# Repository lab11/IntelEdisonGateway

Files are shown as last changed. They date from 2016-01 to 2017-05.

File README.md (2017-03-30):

# Intel Edison-based Gateway
<!--
A gateway design based on Intel Edison, which features two 802.15.4
radios, Ethernet controller, micro SD slot, built-in Wifi and BLE radios.

<img src="https://raw.githubusercontent.com/lab11/IntelEdisonGateway/master/images/edison_front.png" alt="Gateway Edison" width="25%;">&nbsp;&nbsp;&nbsp;&nbsp;&nbsp;&nbsp;&nbsp;&nbsp;&nbsp;
<img src="https://raw.githubusercontent.com/lab11/IntelEdisonGateway/master/images/edison_case_1000x629.jpg" alt="Gateway Edison" width="35%;">
-->
Second generation of Intel Edison Gateway. The gateway supports a wide range 
of radios / connectivity including 802.15.4, Wifi, BLE, Ethernet, LTE and GPS.
The precompiled linux kernel [image](https://github.com/lab11/IntelEdisonGateway/tree/master/kernel_patch/3.10.98/kernel_image) 
(based on Intel release, version 3.10.98) comes with necessary drivers for the
cellular modem and Ethernet controller.

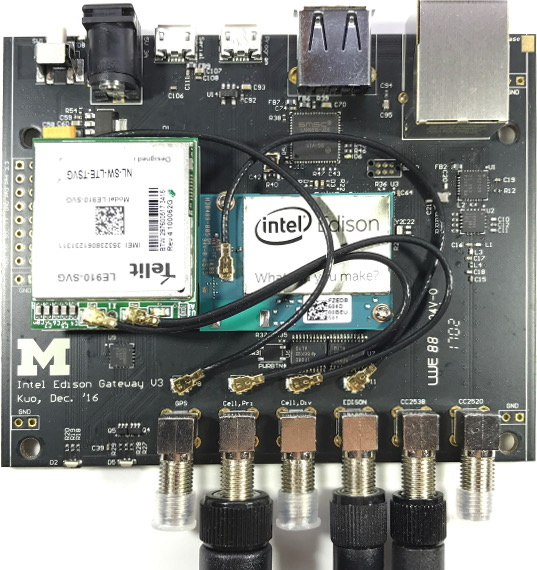
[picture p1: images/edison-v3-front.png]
Gateway Edison
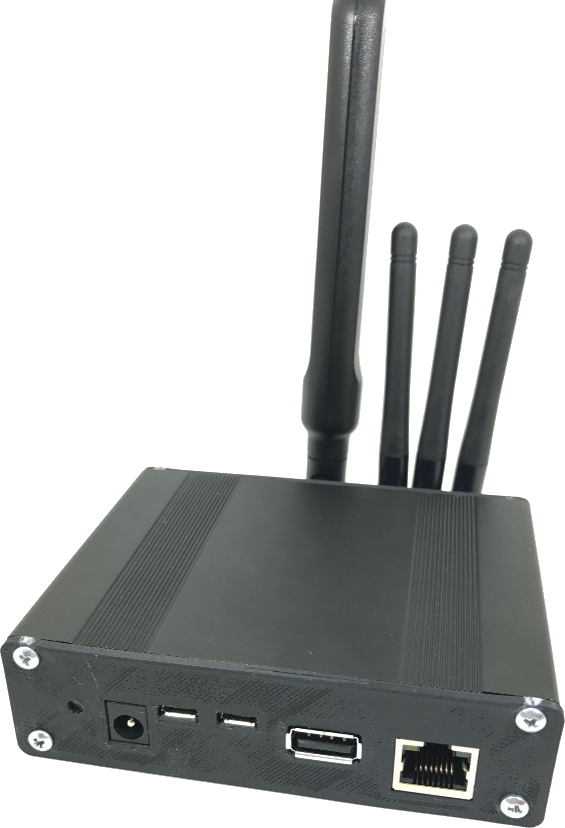
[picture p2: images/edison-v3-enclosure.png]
Gateway Edison Enclosure
 

The onboard cellular modem is [NimbeLink Skywire 4G LTE](http://nimbelink.com/skywire-cellular-modem-lte/),
which supports 100 Mb downlink and 50 Mb uplink and integrated GPS radio.
The cellular radio speaks Qualcomm MSM Interface (QMI), which allows the radio
to be mounted as a network adapter directly in Linux with [libqmi](https://www.freedesktop.org/wiki/Software/libqmi/).

The board is designed to fit in the off-the-shelf extruded aluminum enclosure 
[B2-080BK](http://www.boxenclosures.com/category/product_details.html?product__id=258909).

<!--
[LGSInnovations](https://github.com/LGSInnovations/Edison-Ethernet) has great
documentation of how to use LAN9512 on ubilinux.
The kernel module for smsc95xx (Ethernet controller) can be found [here](https://github.com/LGSInnovations/Edison-Ethernet/releases),
as well as the [installation guide](https://github.com/LGSInnovations/Edison-Ethernet/blob/master/guides/installation.md).

[edison_front]: https://github.com/lab11/IntelEdisonGateway/blob/master/images/edison_front.png "Front"

Pin Out
-------

Header on the left side of the PCB:

| Pin | Signal | | Signal | Pin |
|-----|---|---|---|-----|
| 1 | MISO | | MOSI | 2 |
| 3 | SCLK | | !CS1 | 4 |
| 5 | SDA | | SCL | 6 |
| 7 | RX | | TX | 8 |
| 9 | GP46 | | GP45 | 10  |
| 11  | PA5 | | GP44 | 12  |
| 13  | PA6 | | PA3 | 14  |
| 15  | PA7 | | PA4 | 16  |
| 17  | GND | | GND | 18  |
-->

Pin Out
-------

Header on the left side of the PCB. This is changed from the previous version:

| Pin | Signal  | | Signal  | Pin |
|-----|---|---|---|-----|
| 1 | VCC3.3  | | VSYS3.9 | 2 |
| 3 | PA4 | | PA5 | 4 |
| 5 | PA3 | | GP46 | 6 |
| 7 | GND | | GND | 8 |
| 9 | UART TX | | UART RX | 10  |
| 11  | I2C SCL | | I2C SDA | 12  |
| 13  | SPI CS1 | | SPI CLK | 14  |
| 15  | MOSI | | MISO | 16  |

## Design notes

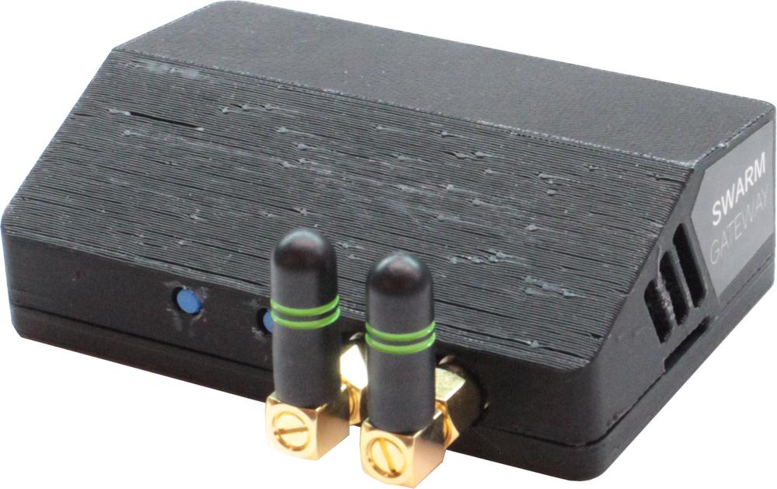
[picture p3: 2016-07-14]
images/edison_case_1000x629.jpg

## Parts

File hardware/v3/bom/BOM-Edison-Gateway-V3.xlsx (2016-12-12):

Designator | Value | Quantity | Tolerance | Rated | Footprint | Description | DigiKey part number | Note
ANT1, ANT2, ANT3, ANT4, ANT5, ANT6 |  | 6 |  |  | 619540-1 | CONN SMA JACK | A120734-ND (https://octopart-clicks.com/click/altium?manufacturer=TE%20Connectivity%20AMP%20Connectors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)
B1 |  | 1 |  |  | 2450BM15A0002 | 2.45 GHz Balun for TI CC253X | 712-1536-1-ND (https://octopart-clicks.com/click/altium?manufacturer=Johanson%20Technology%20Inc.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)
C1, C49, C54, C58 | 100u | 4 | 20% | 10 V | 1206 - POLAR MARKING | 100µF ±20% Molded Tantalum Capacitors 10V 1206 | 478-6251-1-ND (https://octopart-clicks.com/click/altium?sku=478-6251-1-ND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)
C2, C5, C7, C8, C25, C51, C53, C55, C56, C57, C60, C61, C70, C93, C95, C97, C101, C103, C105, C107 | 10u | 20 | 20% | 16 V | 0603 | 10µF ±20% 16V Ceramic Capacitor X6S 0603 | 490-7198-1-ND (https://octopart-clicks.com/click/altium?sku=490-7198-1-ND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)
C3, C4, C6, C9, C13, C14, C19, C24, C26, C32, C33, C34, C35, C36, C37, C38, C39, C63, C64, C65, C66, C67, C68, C69, C71, C72, C74, C75, C76, C77, C78, C79, C80, C81, C82, C83, C84, C85, C86, C87, C88, C89, C91, C106, C108, C111 | 0.1u | 46 | 10% | 16 V | 0402 | 0.10µF ±10% 16V Ceramic Capacitor X7R 0402 | 490-3261-1-ND (https://octopart-clicks.com/click/altium?sku=490-3261-1-ND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)
C10, C20, C21, C30, C31 | 12p | 5 | 2% | 50 V | 0402 | 12pF ±2% 50V Ceramic Capacitor C0G, NP0 0402 | 712-1256-1-ND (https://octopart-clicks.com/click/altium?manufacturer=Johanson%20Technology%20Inc.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)
C11, C29 | 1000p | 2 | 5% | 50 V | 0402 | 1000pF ±5% 50V Ceramic Capacitor C0G, NP0 0402 | 445-6846-1-ND (https://octopart-clicks.com/click/altium?manufacturer=TDK%20Corporation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)
C12, C40, C52, C59, C62, C73, C92, C94, C96, C100, C102, C104 | 1u | 12 | 10% | 16 V | 0402 | 1µF ±10% 16V Ceramic Capacitor X6S 0402 | 445-9086-1-ND (https://octopart-clicks.com/click/altium?manufacturer=TDK%20Corporation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)
C15 | 18p | 1 | 2% | 50 V | 0402 | 18pF ±2% 50V Ceramic Capacitor C0G, NP0 0402 | 712-1264-1-ND (https://octopart-clicks.com/click/altium?manufacturer=Johanson%20Technology%20Inc.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)
C16, C17 | 2.2p | 2 | 5% | 50 V | 0402 | 2.2pF ±0.1pF 50V Ceramic Capacitor C0G, NP0 | 712-1279-1-ND (https://octopart-clicks.com/click/altium?manufacturer=Johanson%20Technology%20Inc.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)
C18 | 0.2p | 1 | 20% | 50 V | 0402 | 0.20pF ±0.05pF 50V Ceramic Capacitor C0G, NP0 0402 | 712-1244-1-ND (https://octopart-clicks.com/click/altium?manufacturer=Johanson%20Technology%20Inc.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)
C22, C23 | 22p | 2 | 2% | 50 V | 0402 | 22pF ±2% 50V Ceramic Capacitor C0G, NP0 0402 | 712-1274-1-ND (https://octopart-clicks.com/click/altium?manufacturer=Johanson%20Technology%20Inc.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)
C27, C28, C109, C110 | 47p | 4 | 5% | 50 V | 0402 | 47pF ±5% 50V Ceramic Capacitor C0G, NP0 0402 | 709-1121-1-ND (https://octopart-clicks.com/click/altium?manufacturer=Johanson%20Dielectrics%20Inc.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)
C41, C42 | 33p | 2 | 5% | 50 V | 0402 | 33pF ±5% 50V Ceramic Capacitor C0G, NP0 0402 | 490-5936-1-ND (https://octopart-clicks.com/click/altium?sku=490-5936-1-ND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)
~~C43~~ | ~~10000p~~ | ~~1~~ | ~~10%~~ | ~~16 V~~ | ~~0402~~ | ~~10000pF ±10% 16V Ceramic Capacitor X7R 0402~~ | ~~490-1313-1-ND~~ (https://octopart-clicks.com/click/altium?sku=490-1313-1-ND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) | ~~DNP~~
C44 | 0.022u | 1 | 10% | 50 V | 0402 | 0.022µF ±10% 50V Ceramic Capacitor X7R 0402 | 490-3884-1-ND (https://octopart-clicks.com/click/altium?sku=490-3884-1-ND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)
C45, C46, C47, C48 | 15p | 4 | 5% | 25 V | 0402 | 15pF ±5% 25V Ceramic Capacitor C0G, NP0 0402 | 490-8171-1-ND (https://octopart-clicks.com/click/altium?sku=490-8171-1-ND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)
C50 | 22u | 1 | 20% | 16 V | 1206 | 22µF ±20% 16V Ceramic Capacitor X5R 1206 | 1276-2728-1-ND (https://octopart-clicks.com/click/altium?sku=1276-2728-1-ND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)
C90 | 220p | 1 | 10% | 50 V | 0402 | 220pF ±10% 50V Ceramic Capacitor X7R 0402 | 399-1030-1-ND (https://octopart-clicks.com/click/altium?sku=399-1030-1-ND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)
C98, C99 | 150u | 2 | 10% | 10 V | 2312 | 150µF ±10% Molded Tantalum Capacitors 10V 2312 | 478-2352-1-ND (https://octopart-clicks.com/click/altium?sku=478-2352-1-ND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)
D1, D3 | Green | 2 |  |  | 0402 - LED | Green 571nm LED Indication - Discrete 2V 0402 (1005 Metric) | 754-1811-1-ND (https://octopart-clicks.com/click/altium?sku=754-1811-1-ND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)
D2, D5, D9 | RGB | 3 |  |  | HSMF | Red, Green, Blue (RGB) 626nm Red, 572nm Green, 470nm Blue LED Indication - Discrete 1.9V Red, 2V Green, 3.4V Blue 4-SMD | 516-2232-1-ND (https://octopart-clicks.com/click/altium?sku=516-2232-1-ND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)
D4, D6 | Orange | 2 |  |  | 0402 - LED | Orange 605nm LED Indication - Discrete 2.1V 0402 | 846-1200-1-ND (https://octopart-clicks.com/click/altium?sku=846-1200-1-ND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)
D7 |  | 1 |  |  | SMAZ5V1 | Zener Diode 5.6V 1W ±5% Surface Mount SMA | SMAZ5V6-FDICT-ND (https://octopart-clicks.com/click/altium?manufacturer=Diodes%20Incorporated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)
D8 | Blue | 1 |  |  | APGA1602 | Blue 463nm LED Indication - Discrete 2.8V 2-SMD | 754-1821-1-ND (https://octopart-clicks.com/click/altium?sku=754-1821-1-ND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)
D10 |  | 1 |  |  | SOT23-3 | Diode Array 1Pair Common Cathode Schottky 40V 200mA (DC) Surface Mount TO-236-3, SC-59, SOT-23-3 | BAS40-05FDICT-ND (https://octopart-clicks.com/click/altium?manufacturer=Diodes%20Incorporated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)
FB1, FB2, FB3, FB4, FB5, FB6, FB7, FB8, FB9, FB10 |  | 10 |  |  | 0603 | FERRITE BEAD 220 OHM 0603 | 490-5225-1-ND (https://octopart-clicks.com/click/altium?sku=490-5225-1-ND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)
J1 |  | 1 |  |  | 2201778-1 | Micro SD Slot | A118117CT-ND (https://octopart-clicks.com/click/altium?manufacturer=TE%20Connectivity%20AMP%20Connectors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)
J2 |  | 1 |  |  | J0011D01BNL | 1x1 Tab-Down RJ45 | 553-1483-ND (https://octopart-clicks.com/click/altium?manufacturer=Pulse%20Electronics%20Corporation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)
J3 |  | 1 |  |  | PJ-102AH | CONN PWR JACK 2.1X5.5MM HIGH CUR | CP-102AH-ND (https://octopart-clicks.com/click/altium?sku=CP-102AH-ND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)
J4, J6 |  | 2 |  |  | Micro USB-B | CONN USB MICRO B RECPT SMT R/A | 609-4616-1-ND (https://octopart-clicks.com/click/altium?sku=609-4616-1-ND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)
J5 |  | 1 |  |  | 292303-2 | USB 2.0 Type A | A105221-ND (https://octopart-clicks.com/click/altium?manufacturer=TE%20Connectivity%20AMP%20Connectors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)
L1 | 4.7n | 1 |  |  | 0402 | 4.7nH Unshielded Multilayer Inductor 300mA 180 mOhm Max 0402 (1005 Metric) | 490-2618-1-ND (https://octopart-clicks.com/click/altium?sku=490-2618-1-ND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)
~~L2~~ | ~~6.8n~~ | ~~1~~ |  |  | ~~0402~~ | ~~6.8nH Unshielded Multilayer Inductor 250mA 320 mOhm Max 0402 (1005 Metric)~~ | ~~712-1419-1-ND~~ (https://octopart-clicks.com/click/altium?manufacturer=Johanson%20Technology%20Inc.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) | ~~DNP~~
L3 | 1n | 1 |  |  | 0402 | 1nH Unshielded Multilayer Inductor 300mA 100 mOhm Max 0402 (1005 Metric) | 490-1073-1-ND (https://octopart-clicks.com/click/altium?sku=490-1073-1-ND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)
L4 | 2n | 1 |  |  | 0402 | 2nH Unshielded Multilayer Inductor 300mA 120 mOhm Max 0402 (1005 Metric) | 490-6558-1-ND (https://octopart-clicks.com/click/altium?sku=490-6558-1-ND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)
L5 | 470n | 1 |  |  | 74404300047 | 470nH Shielded Wirewound Inductor 3.8A 16 mOhm Max 1919 (4848 Metric) | 732-4087-1-ND (https://octopart-clicks.com/click/altium?manufacturer=Wurth%20Electronics%20Inc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)
M1 |  | 1 |  |  | skywire | NimbeLink Skywire cat3, ATT GSM 4G modem |  | Mating connector: 950510-6102-AR (x2)
M2 |  | 1 |  |  | Intel Edison mating | Intel Edison |  | Mating connector: H124603CT-ND
~~P1, P2~~ |  | ~~2~~ |  |  | ~~TC2030-IDC-NLFP~~ | ~~TC2030-MCP-NL~~ |  | ~~Not a part~~
~~P3~~ |  | ~~1~~ |  |  | ~~2x8 header~~ | ~~100 mils standard header~~ | ~~609-3220-ND~~ (https://octopart-clicks.com/click/altium?sku=609-3220-ND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) | ~~DNP~~
~~P4, P5, P6, P7~~ |  | ~~4~~ |  |  | ~~1x2 header~~ | ~~100 mils standard header~~ | ~~3M9447-ND~~ (https://octopart-clicks.com/click/altium?sku=3M9447-ND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) | ~~DNP~~
P8, P9, P10, P11 |  | 4 |  |  | U.FL-R-SMT-1(01) | U.FL, Ultra Miniature Coaxial Connector Receptacle, Male Pin 50 Ohm Surface Mount Solder | H122041-ND (https://octopart-clicks.com/click/altium?manufacturer=Hirose%20Electric%20Co%20Ltd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)
Q1, Q3, Q4, Q5, Q6 |  | 5 |  |  | SOT-353-5 | Common Source Dual N-Channel MOSFET | DMN32D2LDF-7DICT-ND (https://octopart-clicks.com/click/altium?manufacturer=Diodes%20Incorporated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)
Q2 |  | 1 |  |  | TSOT-23 | Load Switch | SI3865DDV-T1-GE3CT-ND (https://octopart-clicks.com/click/altium?manufacturer=Vishay%20Siliconix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)
~~R1, R2, R3, R4, R7, R36~~ | ~~0~~ | ~~6~~ |  |  | ~~0402~~ | ~~RES SMD 0.0 OHM JUMPER 1/5W 0402~~ | ~~541-0.0YBCT-ND~~ (https://octopart-clicks.com/click/altium?sku=541-0.0YBCT-ND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) | ~~DNP~~
R5, R19, R22, R23, R28, R46, R48, R49, R60, R61 | 330 | 10 | 5% |  | 0402 | RES SMD 330 OHM 1% 1/16W 0402 | 541-330LCT-ND (https://octopart-clicks.com/click/altium?sku=541-330LCT-ND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)
R6, R14, R16, R17, R55, R56, R62 | 100k | 7 | 5% |  | 0402 | RES SMD 100K OHM 1% 1/16W 0402 | 541-100KLCT-ND (https://octopart-clicks.com/click/altium?sku=541-100KLCT-ND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)
R8, R9, R10, R13, R15, R30, R31, R33, R34, R35, R39, R47, R54 | 10k | 13 | 5% |  | 0402 | RES SMD 10K OHM 1% 1/16W 0402 | 541-10.0KLCT-ND (https://octopart-clicks.com/click/altium?sku=541-10.0KLCT-ND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)
R11 | 3.9k | 1 | 1% |  | 0402 | RES SMD 3.9K OHM 1% 1/16W 0402 | 311-3.90KLRCT-ND (https://octopart-clicks.com/click/altium?sku=311-3.90KLRCT-ND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)
R12, R26 | 56k | 2 | 1% |  | 0402 | RES SMD 56K OHM 1% 1/16W 0402 | 541-56.0KLCT-ND (https://octopart-clicks.com/click/altium?sku=541-56.0KLCT-ND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)
R18, R27 | 100 | 2 | 5% |  | 0402 | RES SMD 100 OHM 1% 1/16W 0402 | 541-100LCT-ND (https://octopart-clicks.com/click/altium?sku=541-100LCT-ND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)
R20, R29, R37, R53 | 200 | 4 | 5% |  | 0402 | RES SMD 200 OHM 1% 1/16W 0402 | 541-200LCT-ND (https://octopart-clicks.com/click/altium?sku=541-200LCT-ND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)
R21, R24, R58, R59 | 27 | 4 | 1% |  | 0402 | RES SMD 27 OHM 1% 1/16W 0402 | 541-27.0LCT-ND (https://octopart-clicks.com/click/altium?sku=541-27.0LCT-ND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)
R25 | 2.2k | 1 | 1% |  | 0402 | RES SMD 2.2K OHM 1% 1/16W 0402 | 541-2.20KLCT-ND (https://octopart-clicks.com/click/altium?sku=541-2.20KLCT-ND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)
R38 | 12.4k | 1 | 1% |  | 0402 | RES SMD 12.4K OHM 1% 1/16W 0402 | 311-12.4KLRCT-ND (https://octopart-clicks.com/click/altium?sku=311-12.4KLRCT-ND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)
R40, R50 | 1Meg | 2 | 1% |  | 0402 | RES SMD 1M OHM 1% 1/16W 0402 | 541-1.00MLCT-ND (https://octopart-clicks.com/click/altium?sku=541-1.00MLCT-ND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)
R41, R42, R43, R44 | 49.9 | 4 | 1% |  | 0402 | RES SMD 49.9 OHM 1% 1/16W 0402 | 541-49.9LCT-ND (https://octopart-clicks.com/click/altium?sku=541-49.9LCT-ND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)
R45 | 10 | 1 | 1% |  | 0402 | RES SMD 10 OHM 1% 1/16W 0402 | 541-10.0LCT-ND (https://octopart-clicks.com/click/altium?sku=541-10.0LCT-ND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)
R51 | 634k | 1 | 1% |  | 0402 | RES SMD 634K OHM 1% 1/16W 0402 | 541-634KLCT-ND (https://octopart-clicks.com/click/altium?sku=541-634KLCT-ND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)
R52 | 162k | 1 | 1% |  | 0402 | RES SMD 162K OHM 1% 1/16W 0402 | 541-162KLCT-ND (https://octopart-clicks.com/click/altium?sku=541-162KLCT-ND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)
R57 | 12k | 1 | 1% |  | 0402 | RES SMD 12K OHM 1% 1/16W 0402 | 541-12.0KLCT-ND (https://octopart-clicks.com/click/altium?sku=541-12.0KLCT-ND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)
SW1 |  | 1 |  |  | KT11PXSA2M | Tactile Switch SPST-NO Side Actuated Surface Mount, Right Angl | CKN1858CT-ND (https://octopart-clicks.com/click/altium?sku=CKN1858CT-ND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)
~~SW3~~ |  | ~~1~~ |  |  | ~~PTS810~~ | ~~Tactile Switches~~ | ~~CKN10504CT-ND~~ (https://octopart-clicks.com/click/altium?manufacturer=C%26K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) | ~~DNP~~
U1 |  | 1 |  |  | QFN-28 | 2.4 GHZ IEEE 802.15.4/ZIGBEE® RF TRANSCEIVER | 296-38897-1-ND (https://octopart-clicks.com/click/altium?sku=296-38897-1-ND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)
U2 |  | 1 |  |  | QFN-16 | 2.4-GHz Range Extender | 296-37475-1-ND (https://octopart-clicks.com/click/altium?sku=296-37475-1-ND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)
U3 |  | 1 |  |  | QFN56 | A Powerful System-On-Chip for 2.4-GHz IEEE 802.15.4, 6LoWPAN and ZigBee Applications | 296-35797-1-ND (https://octopart-clicks.com/click/altium?sku=296-35797-1-ND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)
U4, U14 |  | 2 |  |  | SOT23-5 | Single Bus Buffer Gate With 3-State Output | 296-11603-1-ND (https://octopart-clicks.com/click/altium?manufacturer=Texas%20Instruments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)
U5, U17 |  | 2 |  |  | QFN-20_N | USB to Full-Handshake UART Interface Chip, UHCI/OHCI/EHCI Compatible, USB 2.0 Compatible, -40 to +85 degC, 20-Pin QFN, Pb-Free, Tape and Reel | 768-1155-ND (https://octopart-clicks.com/click/altium?sku=768-1155-ND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)
U6, U7, U8 |  | 3 |  |  | TSSOP-20 | TXS0108E-Q1 8-Bit Bi-directional, Level-Shifting, Voltage Translator for Open-Drain and Push-Pull Applications | 296-42401-1-ND (https://octopart-clicks.com/click/altium?sku=296-42401-1-ND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)
U9 |  | 1 |  |  | TQFN-16 | 6-Channel High-Speed Logic-Level Translators | MAX13035EETE+-ND (https://octopart-clicks.com/click/altium?manufacturer=Maxim%20Integrated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)
U10 |  | 1 |  |  | QFN-64 | USB 2.0 Hub and 10/100 Ethernet Controller | LAN9513-JZX-ND (https://octopart-clicks.com/click/altium?sku=LAN9513-JZX-ND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)
U11 |  | 1 |  |  | VSON | 3-A Step-Down Converter With Hiccup Short-Circuit Protection In 2 × 2 QFN Package | 296-40830-1-ND (https://octopart-clicks.com/click/altium?sku=296-40830-1-ND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)
U12 |  | 1 |  |  | SOT150P700X180-5N | LP387x 0.8-A Fast Ultra-Low-Dropout Linear Regulators | LP3874EMP-3.3/NOPBCT-ND (https://octopart-clicks.com/click/altium?manufacturer=Texas%20Instruments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)
U13 |  | 1 |  |  | S-PVSON-N10 | High-Speed USB 2.0 (480-Mbps) 1:2 Multiplexer – Demultiplexer Switch With Single Enable | 296-21360-6-ND (https://octopart-clicks.com/click/altium?sku=296-21360-6-ND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)
U15, U16 |  | 2 |  |  | U-DFN3030-8 | 0.5A DUAL CHANNEL CURRENT-LIMITED POWER SWITCH WITH OUTPUT DISCHARGE | AP2152AFGEG-7DICT-ND (https://octopart-clicks.com/click/altium?manufacturer=Diodes%20Incorporated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)
Y1, Y3 |  | 2 |  |  | FA-128 | MHz Range Crystal Unit | SER4079CT-ND (https://octopart-clicks.com/click/altium?sku=SER4079CT-ND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)
Y2 |  | 1 |  |  | ABS05 | 32768 Hz SMD Low profile crystal | 535-11899-1-ND (https://octopart-clicks.com/click/altium?sku=535-11899-1-ND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)
Y4 |  | 1 |  |  | ABM8 | Crystal 25.0000MHz 20ppm 18pF 50 Ohm | 535-9140-1-ND (https://octopart-clicks.com/click/altium?sku=535-9140-1-ND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)

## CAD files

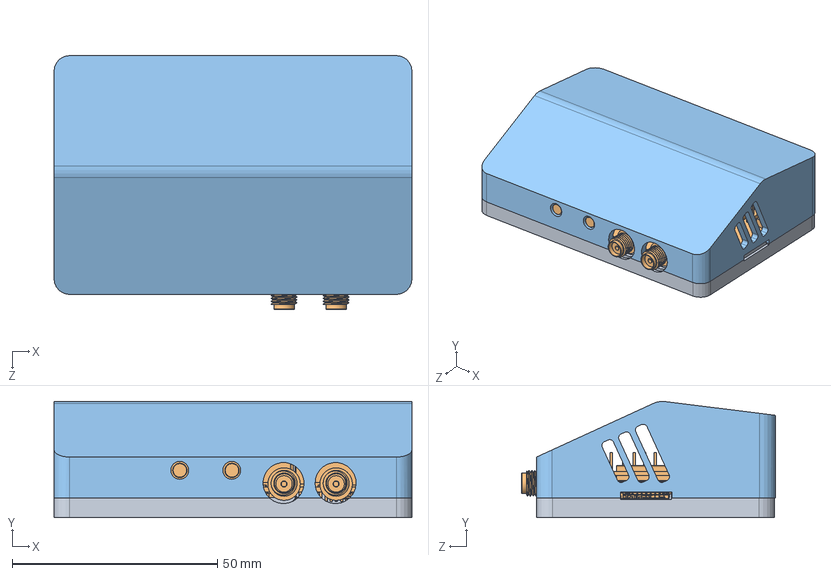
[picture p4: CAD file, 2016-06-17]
3d/gateway_in_case.SLDASM
87.3 x 28.3 x 61.9 mm
case_bottom
edison_gateway
case_top

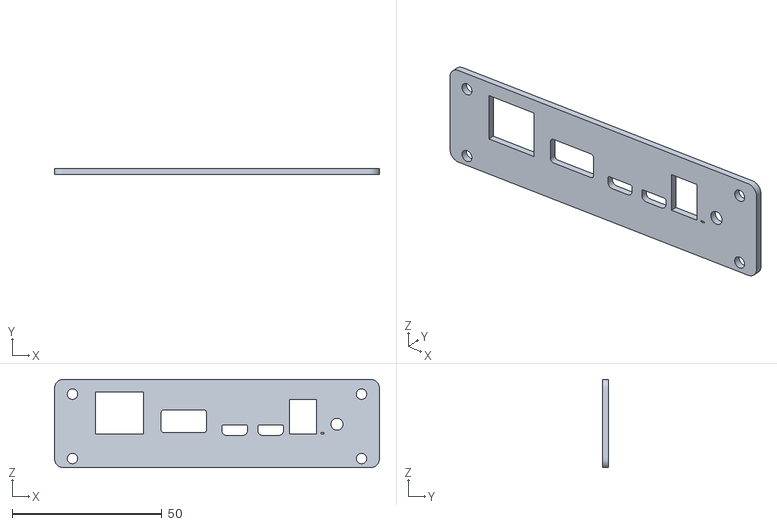
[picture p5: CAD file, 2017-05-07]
3d/v3/case_v3_plate_front_v7.STL
108.5 x 2.00 x 29.5

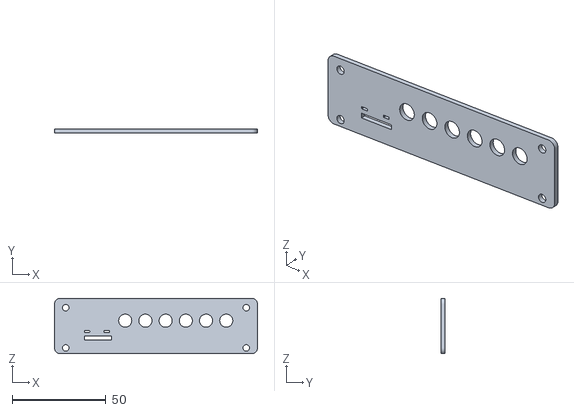
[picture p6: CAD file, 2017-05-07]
3d/v3/case_v3_plate_antenna_v7.STL
108.5 x 2.00 x 29.5

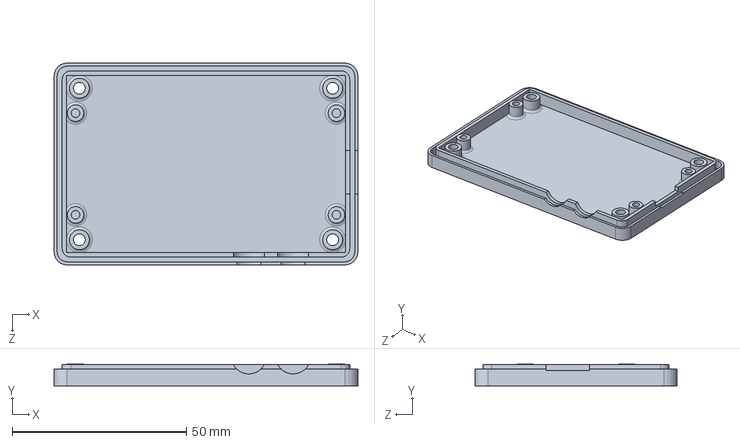
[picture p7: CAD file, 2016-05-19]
3d/case_bottom.SLDPRT
87.3 x 6.22 x 58.0 mm

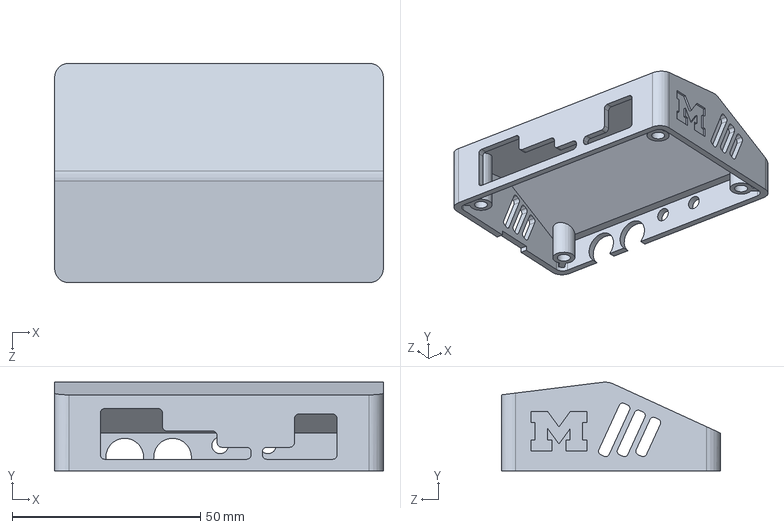
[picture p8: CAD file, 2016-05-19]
3d/case_top.SLDPRT
87.3 x 23.5 x 58.2 mm

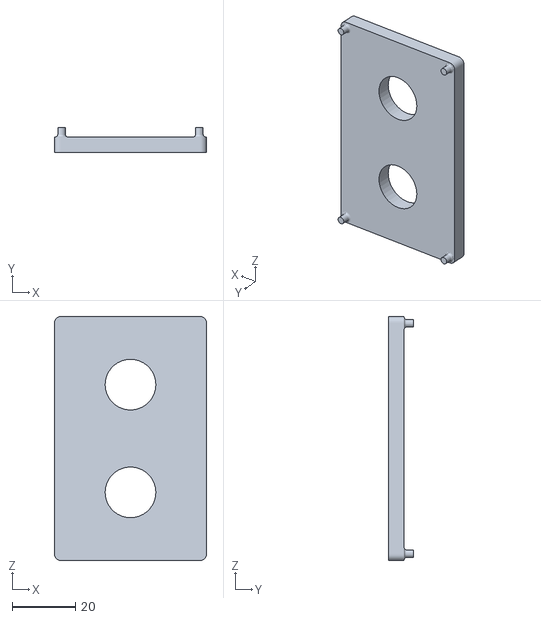
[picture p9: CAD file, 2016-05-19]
3d/case_screw_inserts_jig_top_v1.STL
48.0 x 8.00 x 77.0

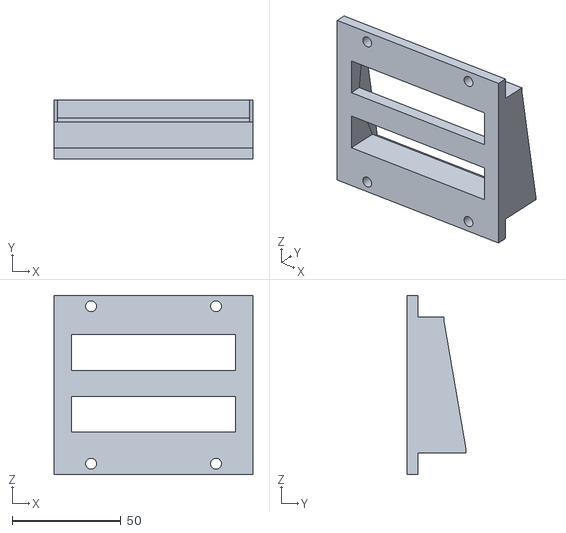
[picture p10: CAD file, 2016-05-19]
3d/case_screw_inserts_jig_v2.STL
91.3 x 27.0 x 82.2

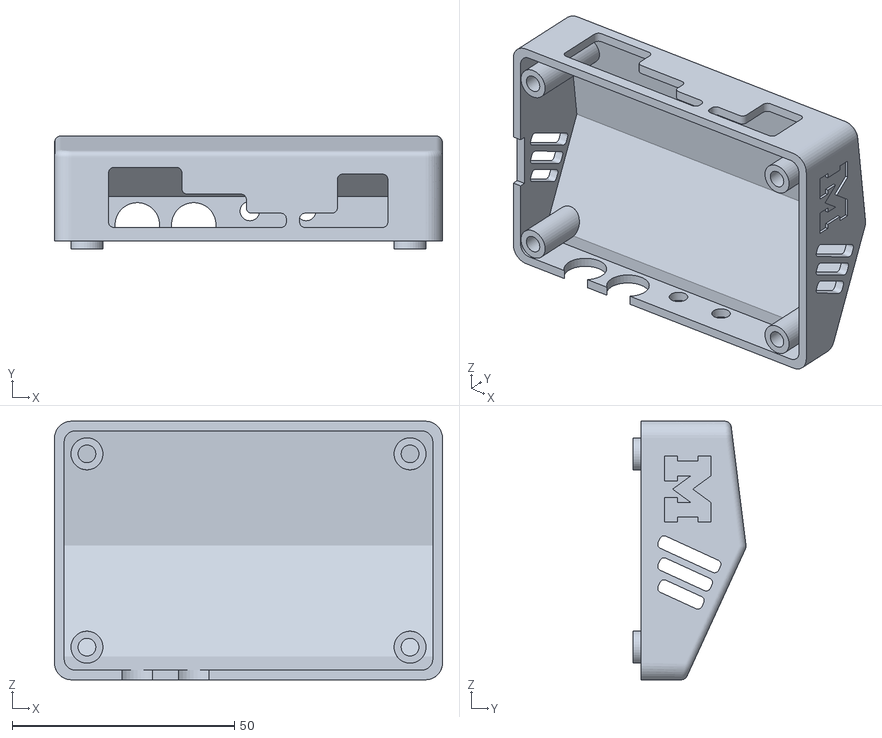
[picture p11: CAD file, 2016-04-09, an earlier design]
3d/case_top_v2.STL
87.3 x 25.5 x 58.2

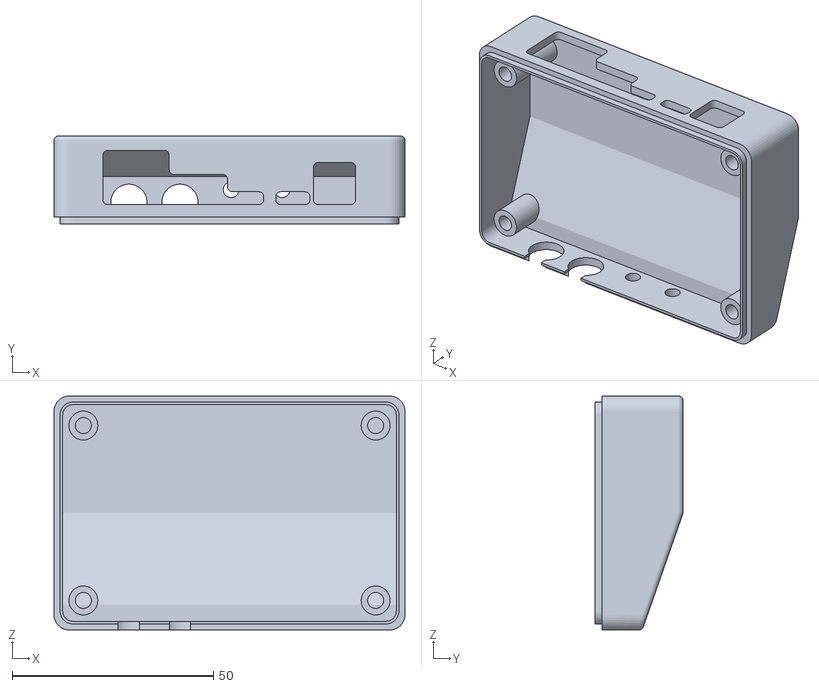
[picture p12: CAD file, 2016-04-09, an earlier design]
3d/case_top_v1.STL
87.3 x 22.0 x 58.2

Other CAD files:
3d/v3/case_v3_plate_antenna.SLDPRT
3d/v3/case_v3_plate_front.SLDPRT
3d/case_top_v6.STL
3d/case_bottom_v2.STL
3d/case_screw_inserts_jig.SLDPRT
3d/case_screw_inserts_jig_top.SLDPRT
3d/case_top_v5.STL
3d/case_bottom_v1.STL
3d/case_top_v3.STL
3d/case_screw_inserts_jig_v1.STL
3d/case_top_v4.STL

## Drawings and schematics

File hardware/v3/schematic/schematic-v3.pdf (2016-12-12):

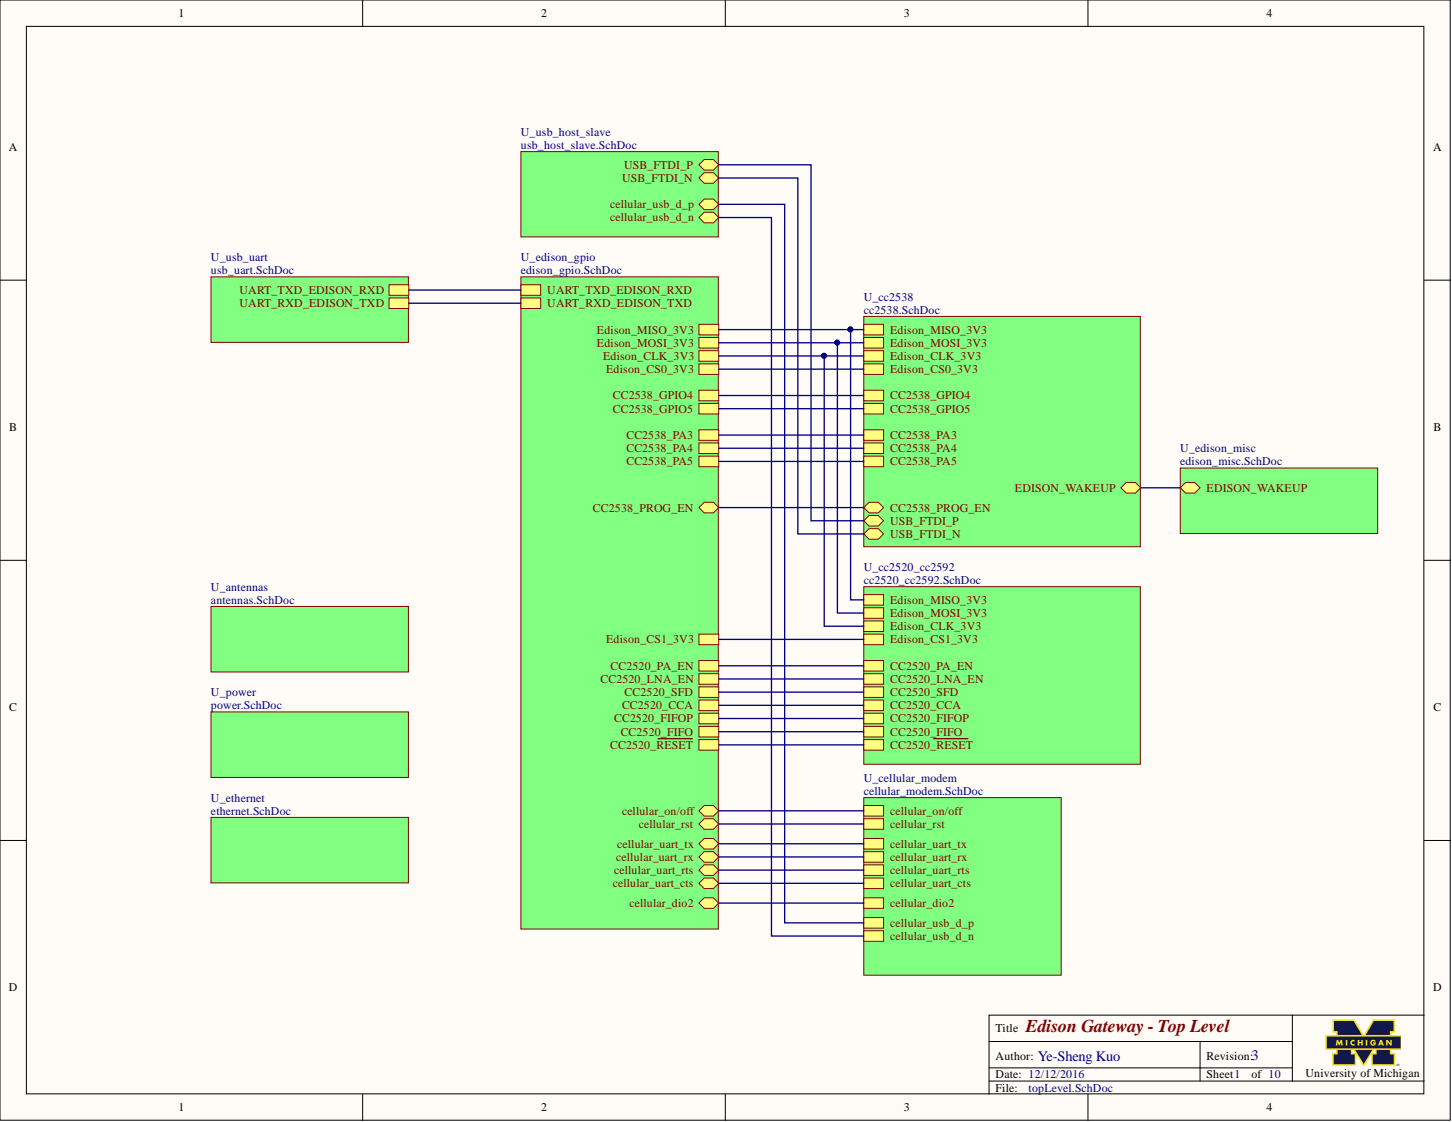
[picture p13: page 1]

Edison Gateway - Top Level Title | University of Michigan

Author: Ye-Sheng Kuo | Revision:
Date: | Sheet of

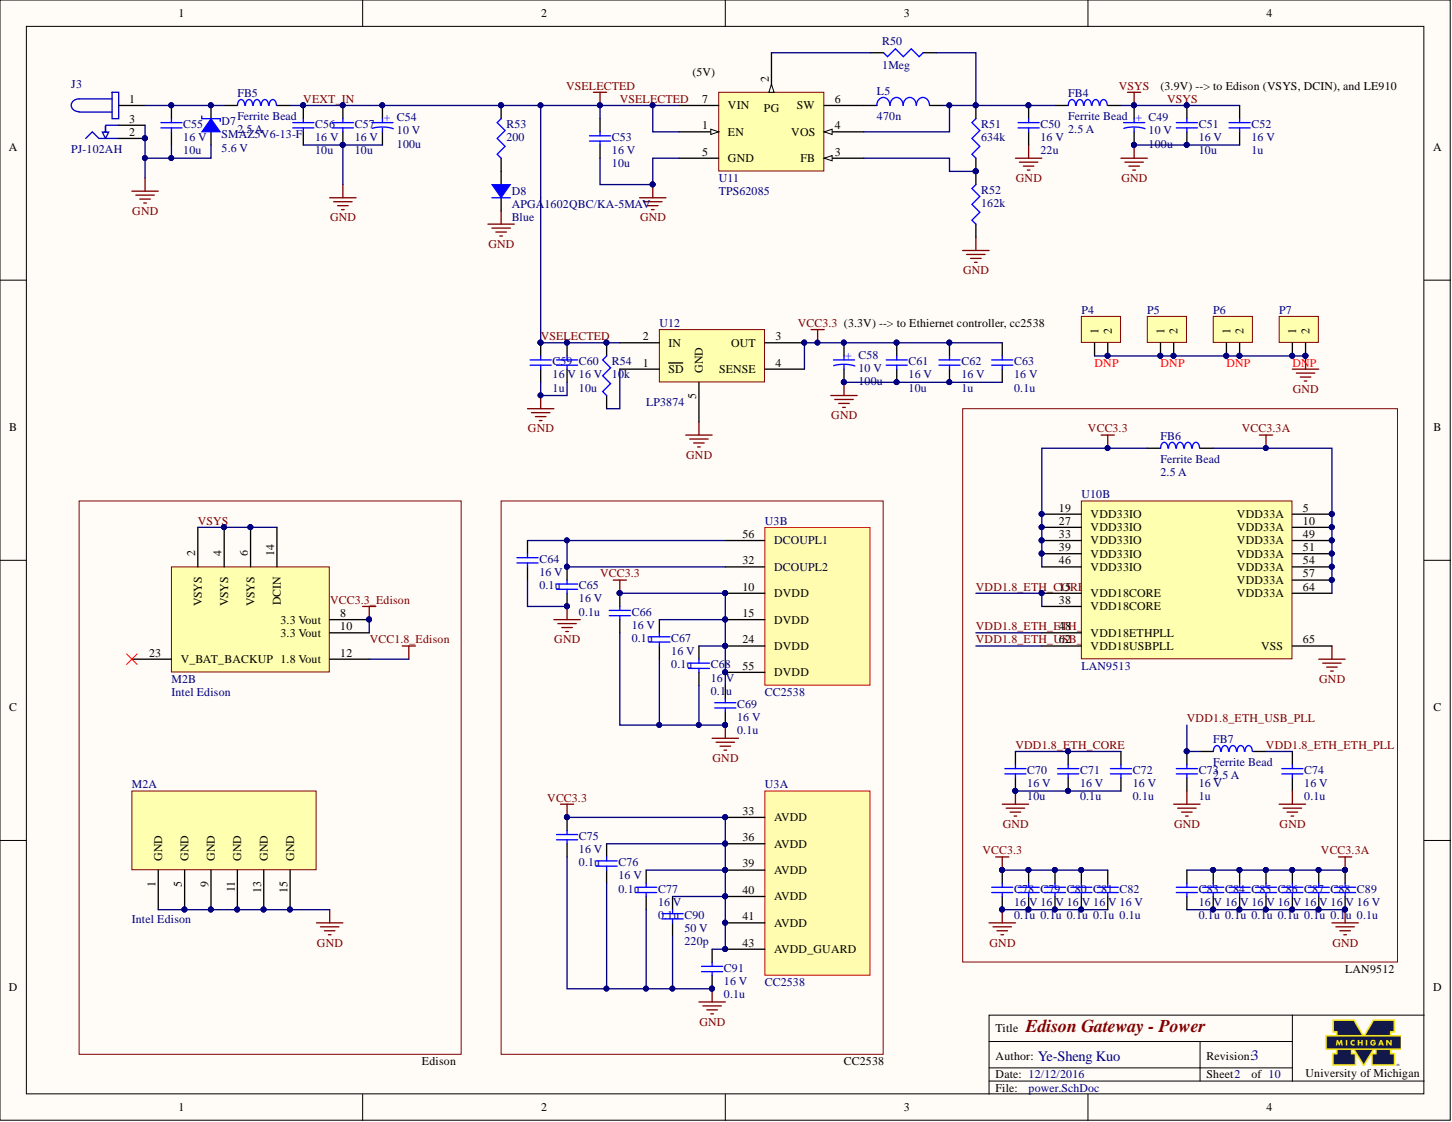
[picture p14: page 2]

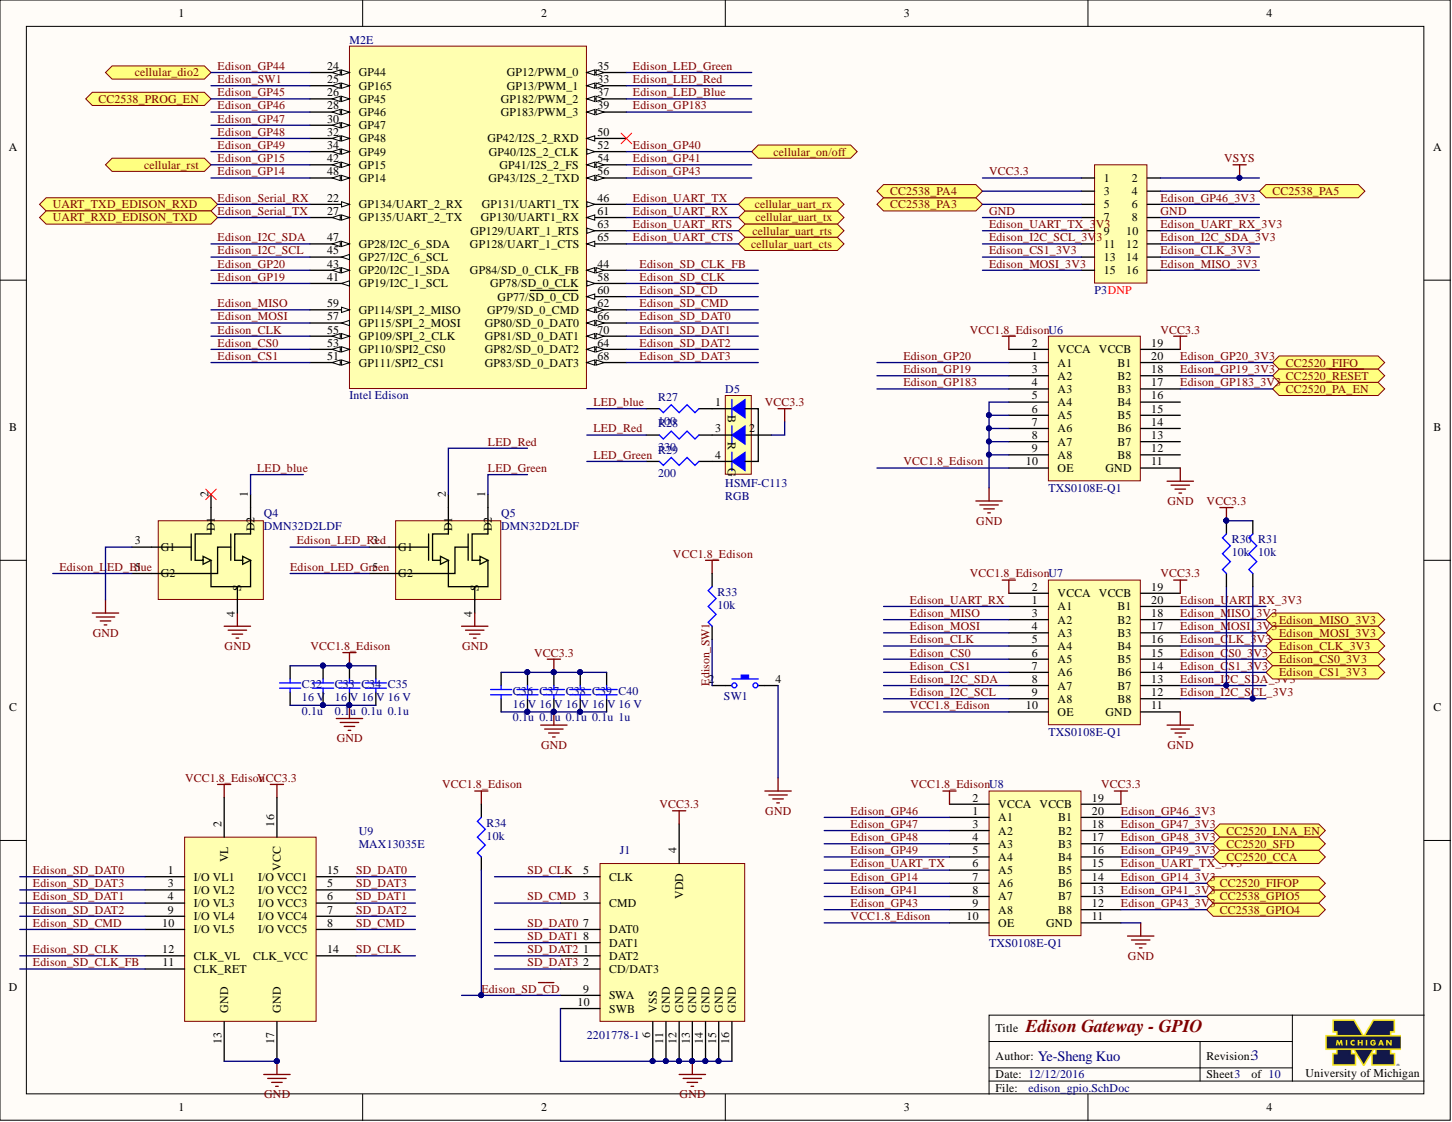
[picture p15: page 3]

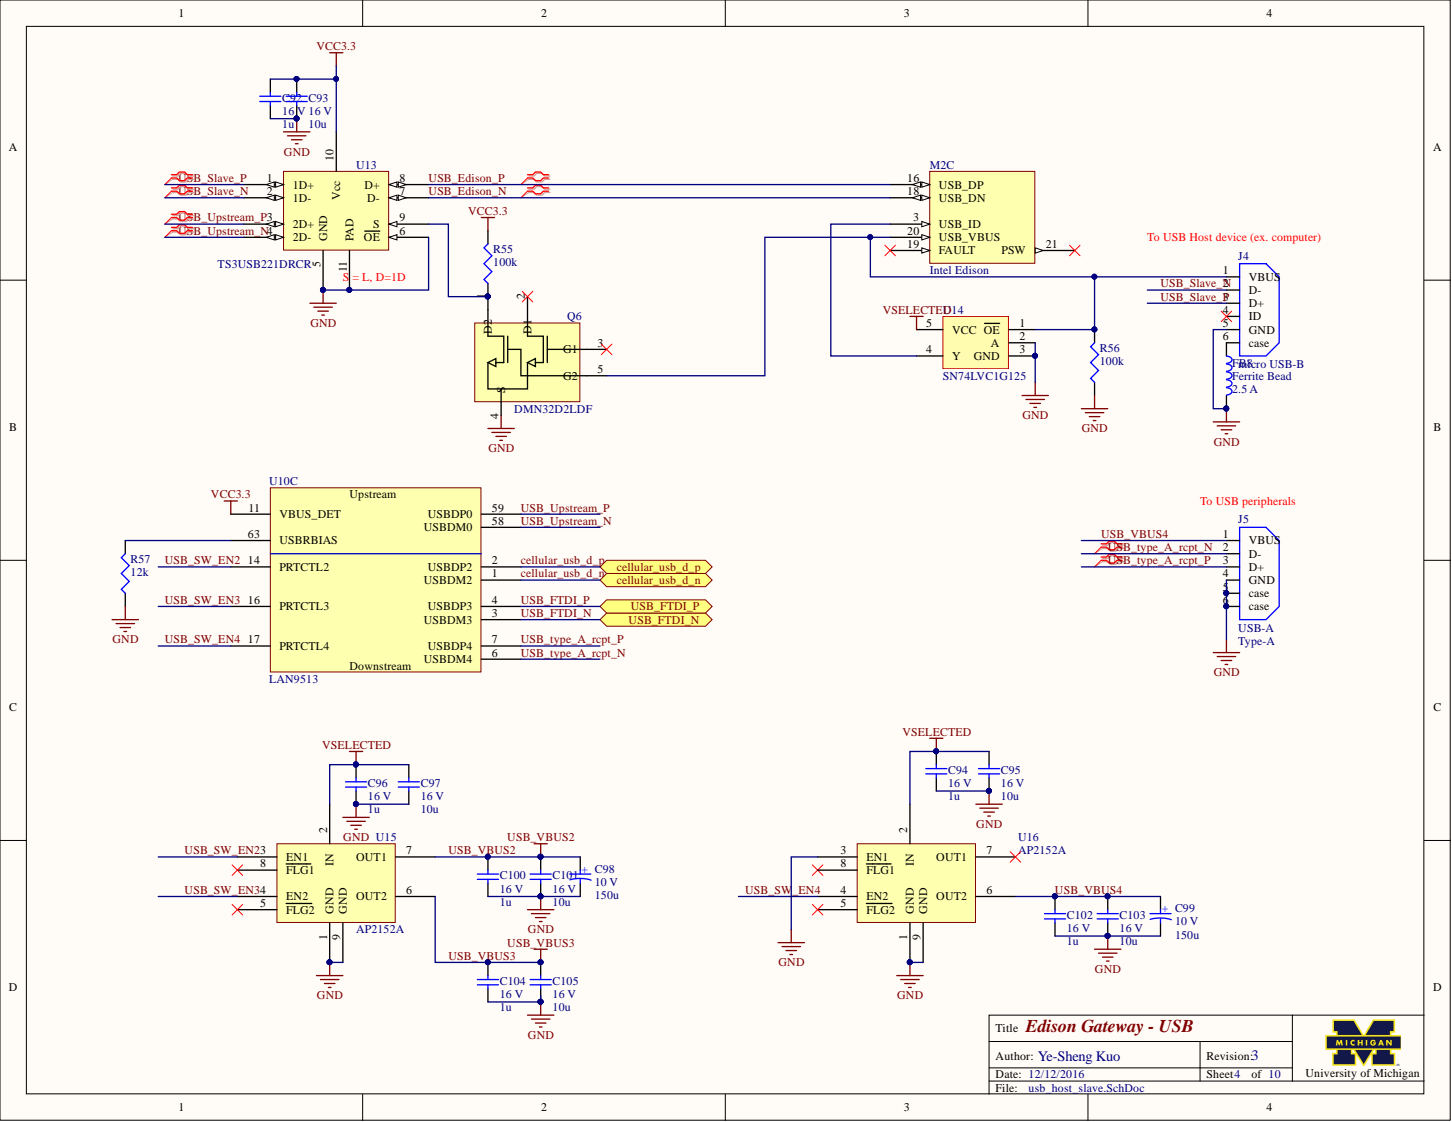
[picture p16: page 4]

To USB Host device (ex. computer)

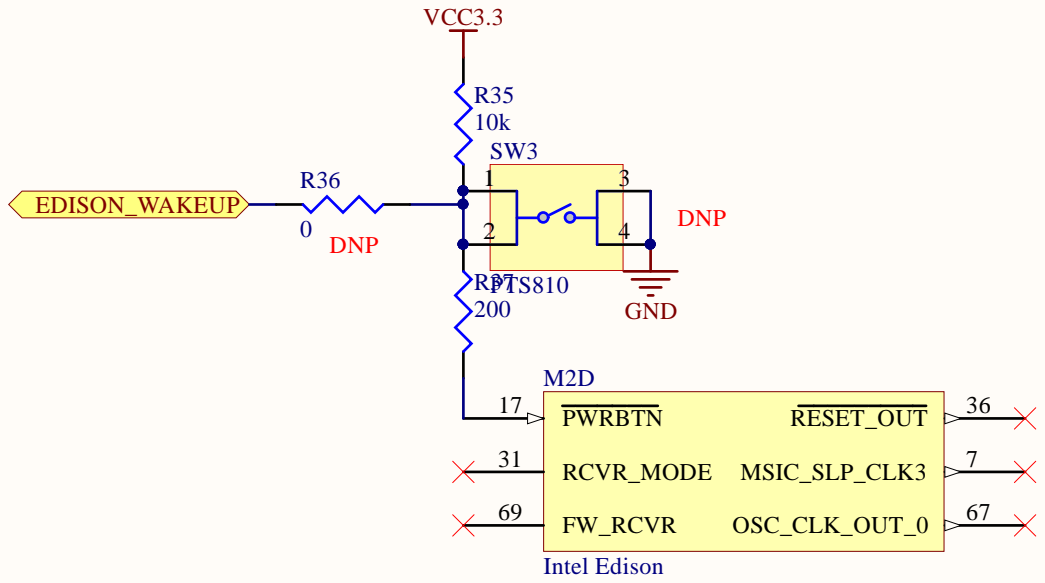
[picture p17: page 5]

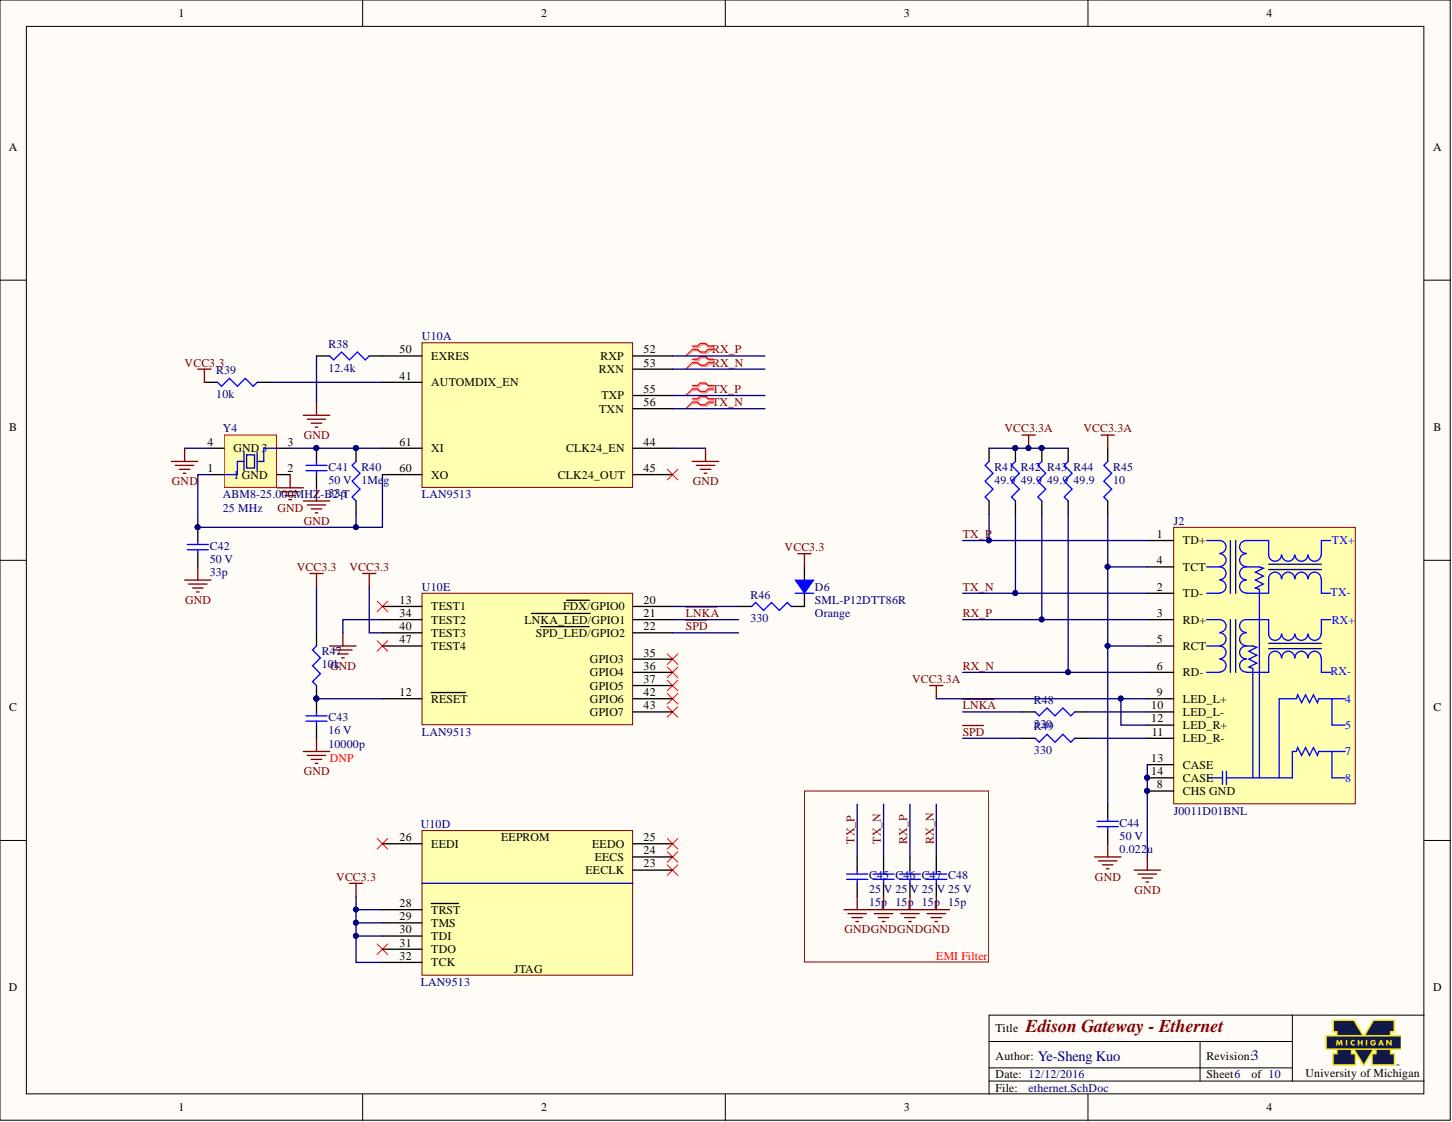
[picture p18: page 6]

TD+ 1 TCT 4

TD- 2 RD+ 3 RCT 5

TEST3 40

GNDGNDGNDGND | C45 | C46 | C47 | C48

TMS 29
TDI 30
TDO 31

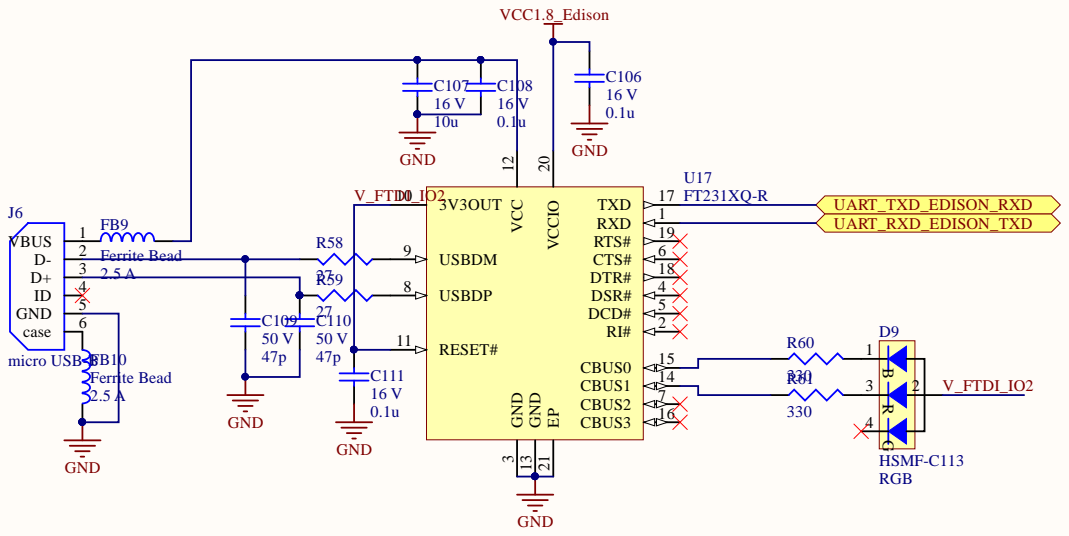
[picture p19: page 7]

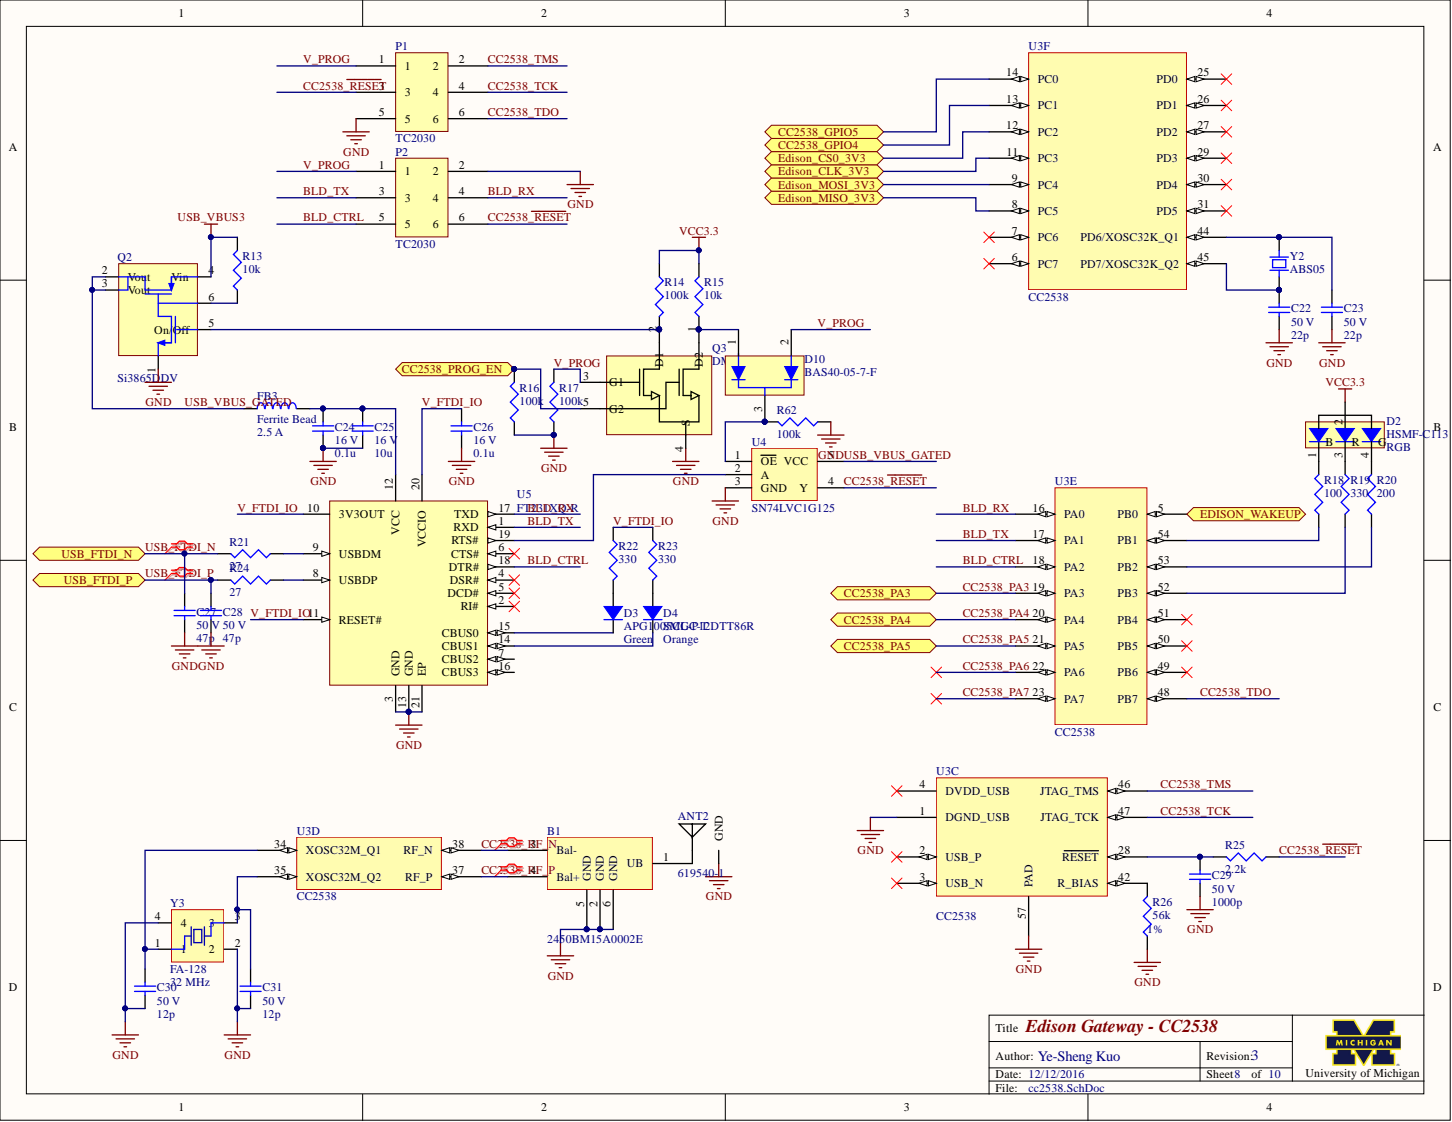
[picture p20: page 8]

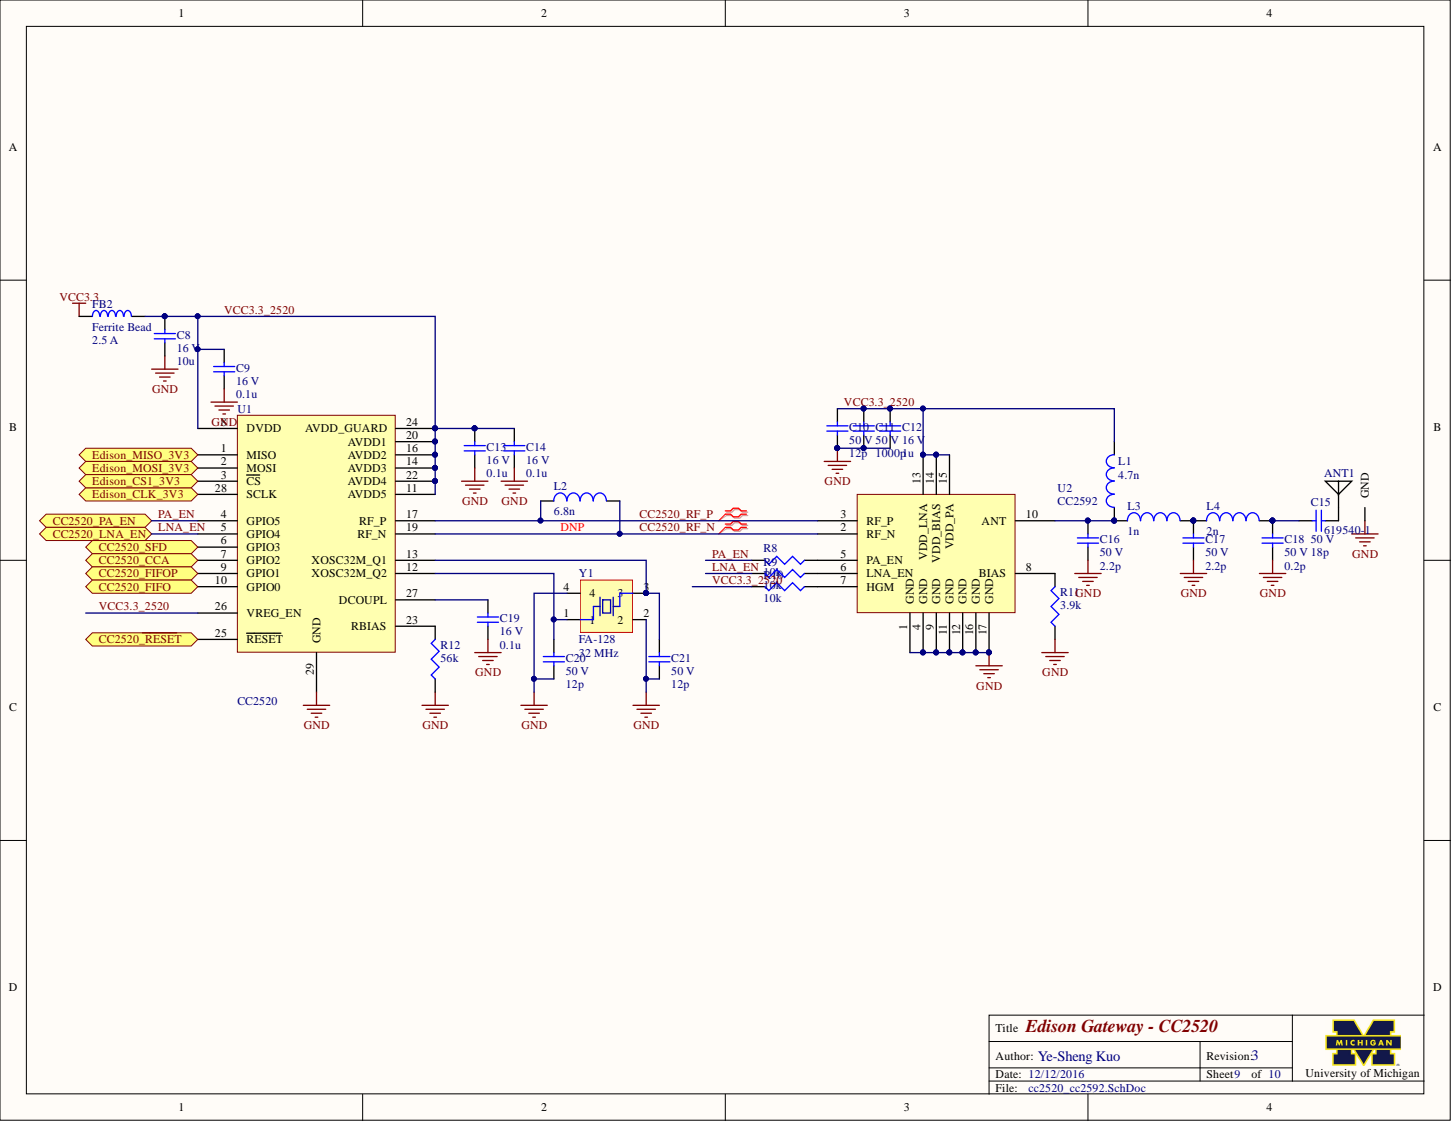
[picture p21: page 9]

Edison Gateway - CC2 52 0 T i t l e | U n i vers i t y of Mich i gan

A u t h or: Ye-S h e n g Ku o | Rev i s i o n :

/ / | Sheet o f

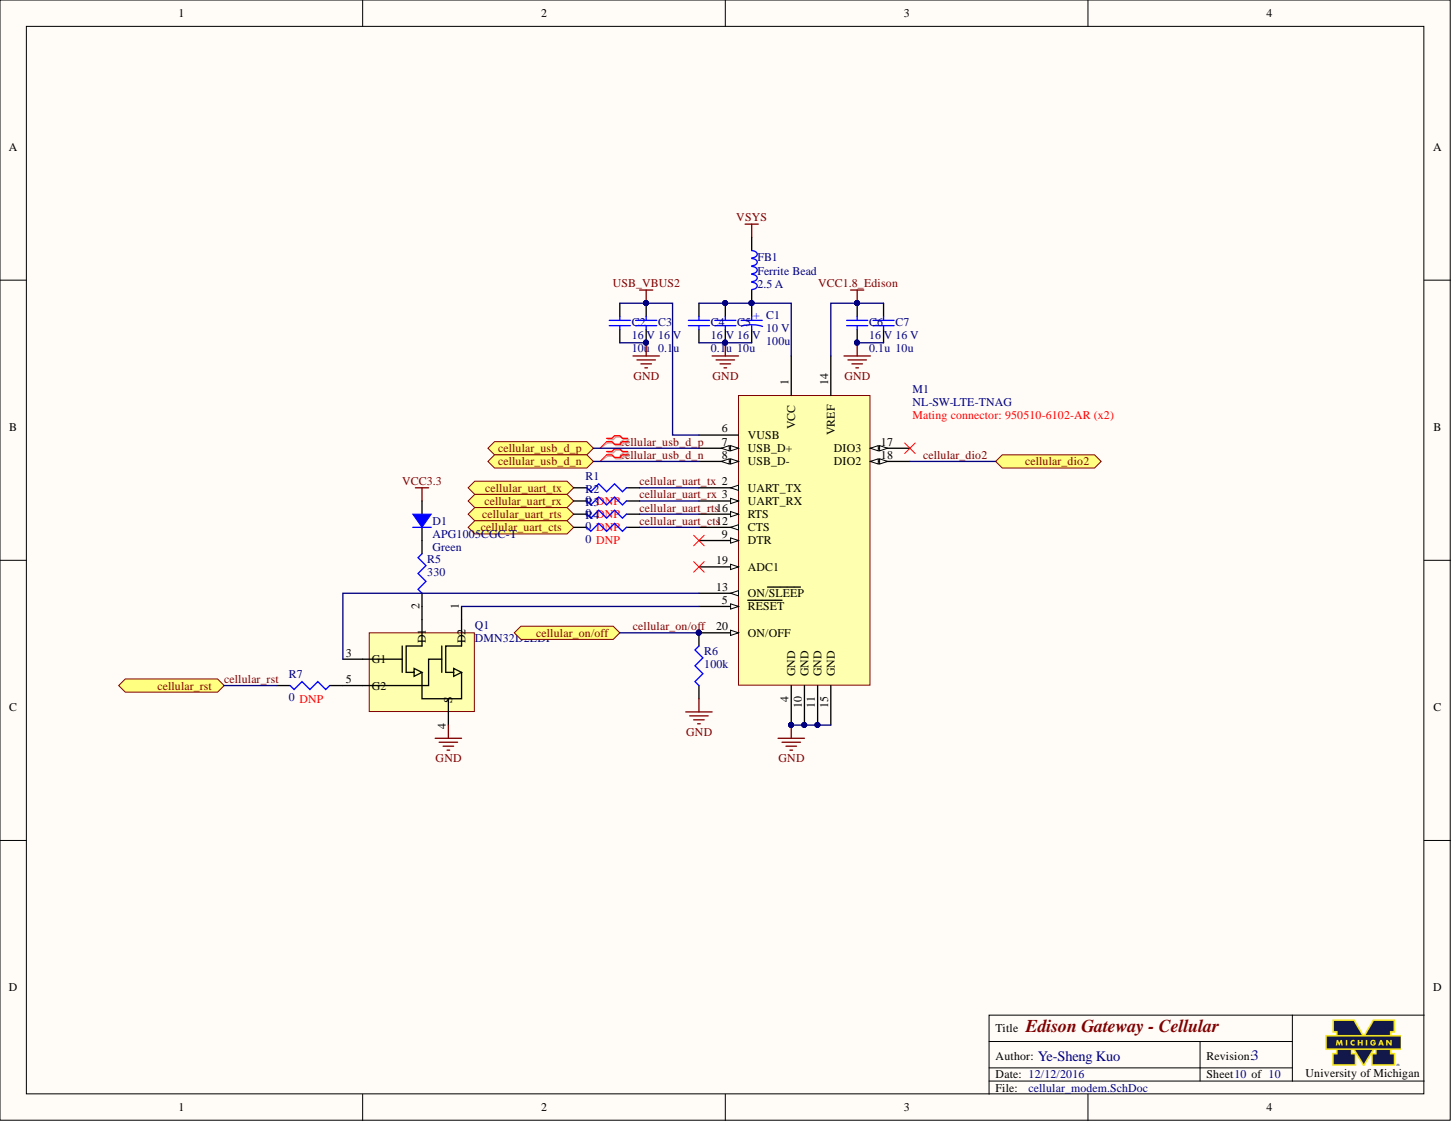
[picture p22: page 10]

Mating connector: 950510-6102-AR (x2) VCC 1

NL-SW-LTE-TNAG

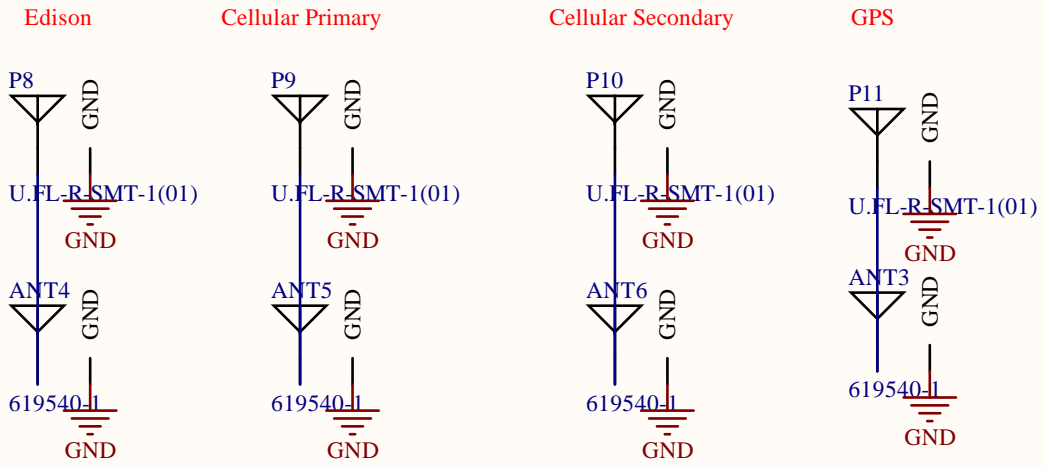
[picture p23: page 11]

T i t l e | U n i vers i t y of Mich i gan

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

/ / | Sheet o f

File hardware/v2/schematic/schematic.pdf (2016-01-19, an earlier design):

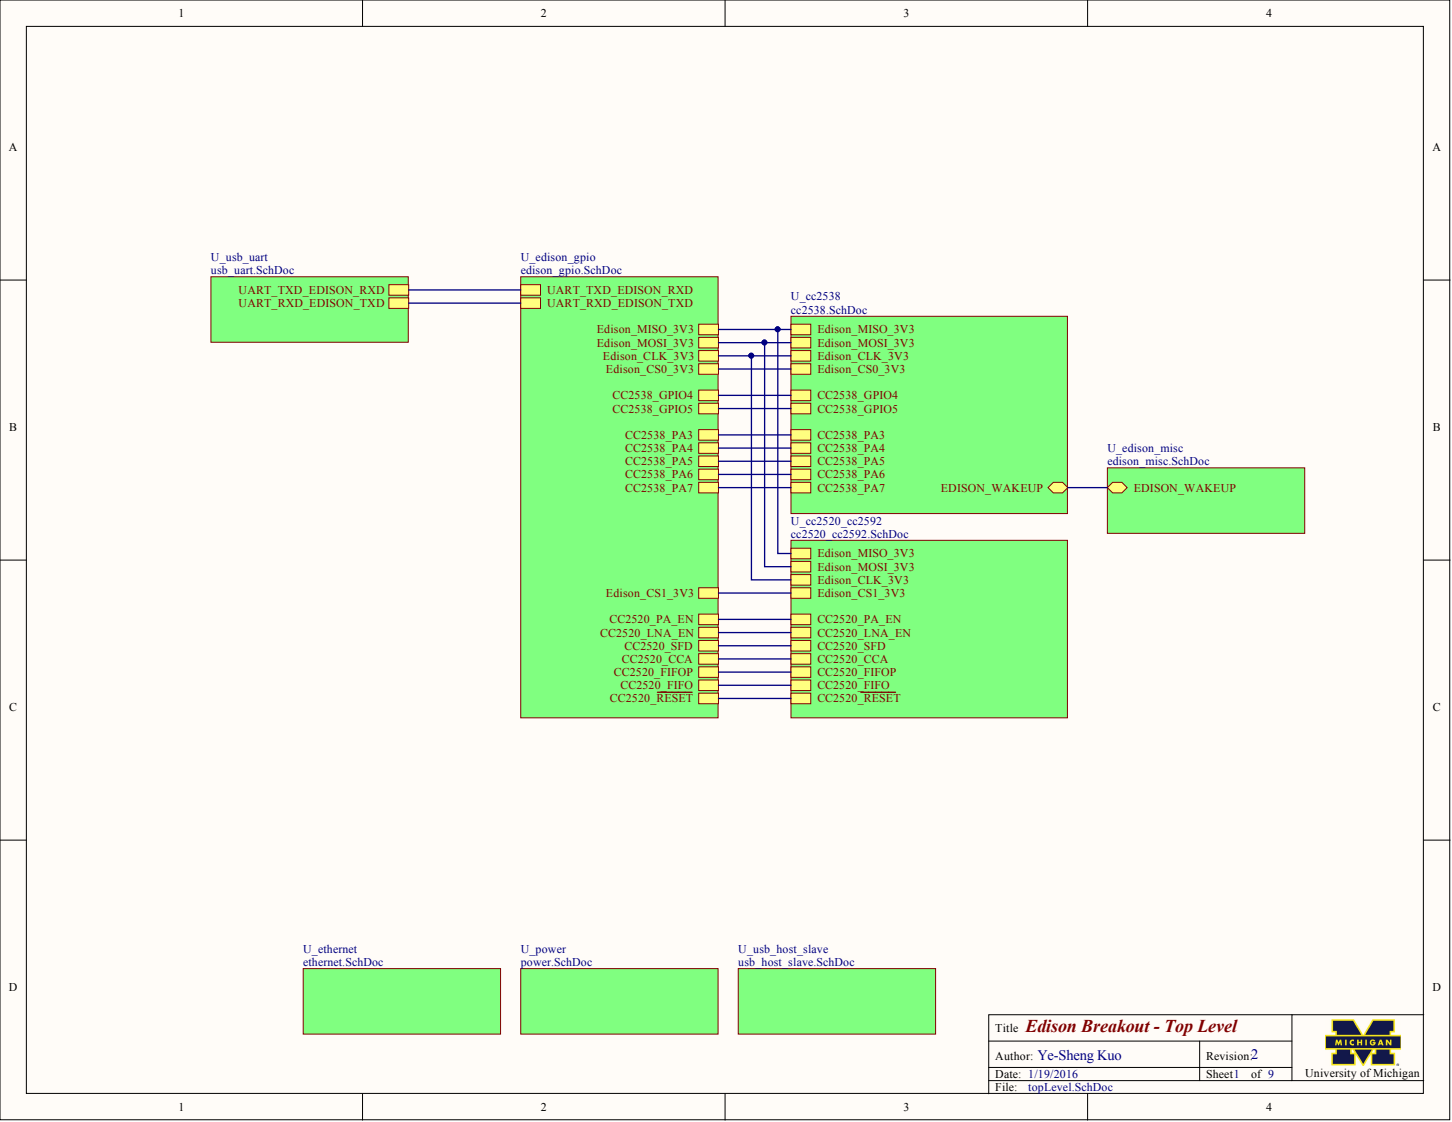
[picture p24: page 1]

Edison Breakout - Top Level Title | University of Michigan

Author: Ye-Sheng Kuo | Revision:
Date: | Sheet of


(4V) --> to Edison (VSYS, DCIN)
VSYS

10 | uF | PGND 1

PAD 9


A7 8
A8 9


USB_VBUS 20

To USB Host device (ex. computer)

C74 | C75
1 uF



2 9
3 0
3 1

Edison Brea kout - Ethernet T i t l e | U n i vers i t y of Mich i gan

A u t h or: Y e-S h e n g Ku o | Rev i s i o n :

/ / | Sheet o f




Edison Brea kout - CC2 52 0 T i t l e | U n i vers i t y of Mich i gan

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

/ / | Sheet o f

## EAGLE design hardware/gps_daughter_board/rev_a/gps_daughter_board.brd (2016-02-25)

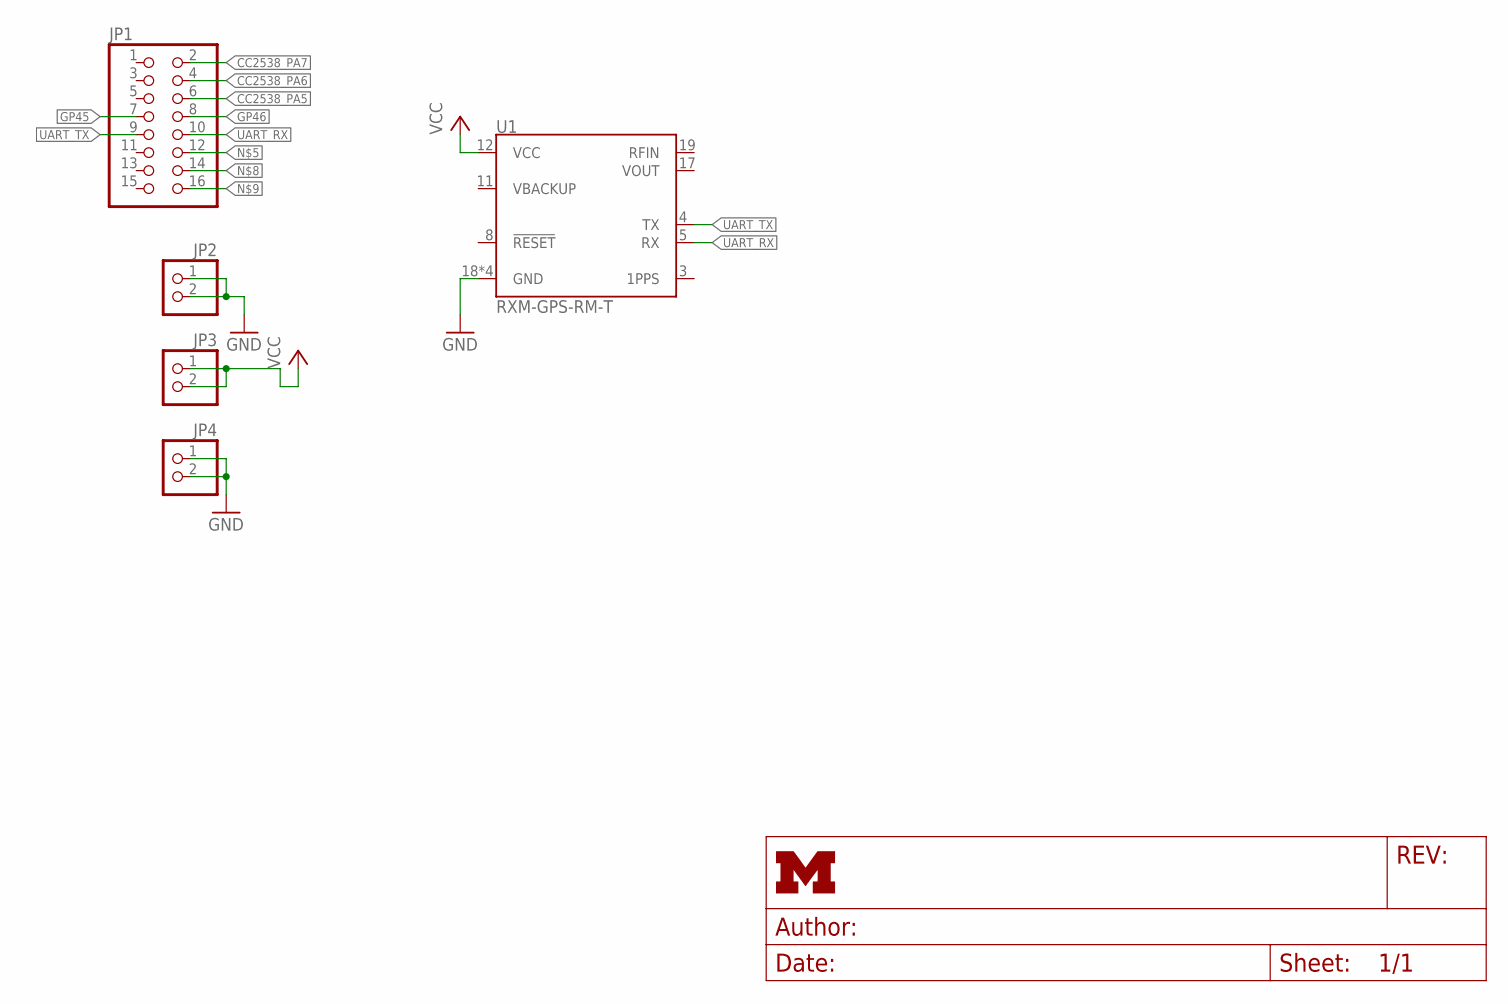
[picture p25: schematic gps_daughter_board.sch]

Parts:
JP1: PINHD-2X8; 2X08
JP2, JP3, JP4: PINHD-1X2; 1X02
U1: RXM-GPS-RM-T

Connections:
CC2538_PA5: JP1.6
CC2538_PA6: JP1.4
CC2538_PA7: JP1.2
GND: JP2.1, JP2.2, JP4.1, JP4.2, U1.18 (GND), U1.20 (GND), U1.21 (GND), U1.22 (GND)
GP45: JP1.7
GP46: JP1.8
UART_RX: JP1.10, U1.5 (RX)
UART_TX: JP1.9, U1.4 (TX)
VCC: JP3.1, JP3.2, U1.12 (VCC)

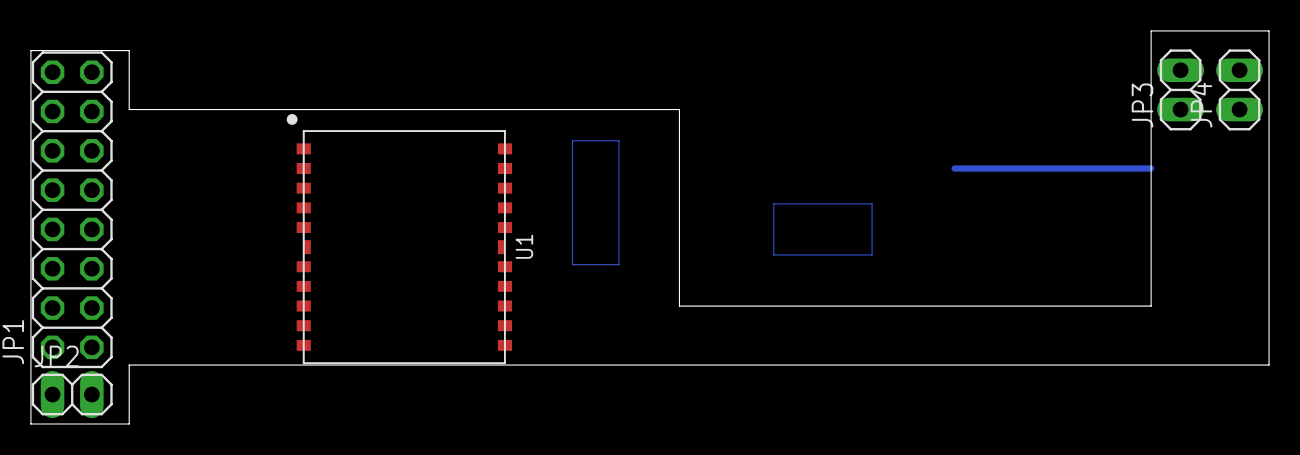
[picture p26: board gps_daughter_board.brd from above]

Board: 2 copper layers, 80.0 x 25.4 mm, 5 parts (0 on the bottom side), 4 nets.

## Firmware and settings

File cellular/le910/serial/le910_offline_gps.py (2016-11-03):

import time
import le910_serial
import signal
import sys

def main():
    try:
        le910 = le910_serial.le910_serial()
    except:
        exit()

    def signal_handler(signal, frame):
        print('Exiting program...')
        le910.stop()
        sys.exit(0)
    signal.signal(signal.SIGINT, signal_handler)

    print('Start location service... '),
    le910.write('start_location_service')
    print (le910.get_data_block())

    print('Set active GPS antenna...'),
    le910.write('active_gps_antenna')
    print (le910.get_data_block())

    print('Get unsolicited data... '),
    le910.write('unsolicited_nmea_data')
    print (le910.get_data_block())

    trial = 1000
    gps_data_valid = False

    while (trial > 0) and (not gps_data_valid):
        tmp = le910.get_data_block()
        print('Data received from GPS: {:}'.format(tmp)), 
        tmp = tmp.split(',')
        if len(tmp[1]) > 0:
            print ('valid data')
            gps_data_valid = True
        else:
            print ('invalid data')
        trial -= 1

    print('Stop unsolicited data...')
    le910.write('stop_unsolicited_nmea_data')
    time.sleep(3)
    le910.clear_data_buf()

    if gps_data_valid:
        le910.write('gps_acquired_position')
        gps_location = le910_serial.gps_info(le910.get_data_block())
        print(gps_location)
        

    print('Stop location service... '),
    le910.write('stop_location_service')
    print (le910.get_data_block())

    le910.stop()
        
if __name__=='__main__':
    main()

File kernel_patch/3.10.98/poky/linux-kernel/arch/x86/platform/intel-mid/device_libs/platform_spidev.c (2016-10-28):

/*
 * platform_spidev.c: spidev platform data initilization file
 *
 * (C) Copyright 2014 Intel Corporation
 * Author: Dan O'Donovan <dan@emutex.com>
 *
 * This program is free software; you can redistribute it and/or
 * modify it under the terms of the GNU General Public License
 * as published by the Free Software Foundation; version 2
 * of the License.
 */

#include <linux/spi/spi.h>
#include <linux/spi/intel_mid_ssp_spi.h>
#include <asm/intel-mid.h>
#include <linux/gpio.h>
#include <linux/lnw_gpio.h>
#include "platform_spidev.h"

static void tng_ssp_spi_cs_control(u32 command);
static void tng_ssp_spi_platform_pinmux(void);

//static int tng_ssp_spi2_FS_gpio = 111;
// Ye-Sheng, 10/27/16
static int tng_ssp_spi2_FS_gpio = 110;

static struct intel_mid_ssp_spi_chip chip = {
	.burst_size = DFLT_FIFO_BURST_SIZE,
	.timeout = DFLT_TIMEOUT_VAL,
	/* SPI DMA is currently usable on Tangier */
	.dma_enabled = true,
	.cs_control = tng_ssp_spi_cs_control,
	.platform_pinmux = tng_ssp_spi_platform_pinmux,
};

static void tng_ssp_spi_cs_control(u32 command)
{
    // Ye-Sheng, 10/27/16
	//gpio_set_value(tng_ssp_spi2_FS_gpio, (command != 0) ? 1 : 0);
}

static void tng_ssp_spi_platform_pinmux(void)
{
    // Ye-Sheng, 10/27/16
	//int err;
	//int saved_muxing;
	///* Request Chip Select gpios */
	//saved_muxing = gpio_get_alt(tng_ssp_spi2_FS_gpio);

	//lnw_gpio_set_alt(tng_ssp_spi2_FS_gpio, LNW_GPIO);
	//err = gpio_request_one(tng_ssp_spi2_FS_gpio,
	//		GPIOF_DIR_OUT|GPIOF_INIT_HIGH, "Arduino Shield SS");
	//if (err) {
	//	pr_err("%s: unable to get Chip Select GPIO,\
	//			fallback to legacy CS mode \n", __func__);
	//	lnw_gpio_set_alt(tng_ssp_spi2_FS_gpio, saved_muxing);
	//	chip.cs_control = NULL;
	//	chip.platform_pinmux = NULL;
	//}
}

void __init *spidev_platform_data(void *info)
{
	struct spi_board_info *spi_info = info;

	if (!spi_info) {
		pr_err("%s: invalid info pointer\n", __func__);
		return NULL;
	}

	spi_info->mode = SPI_MODE_0;

	spi_info->controller_data = &chip;
	spi_info->bus_num = FORCE_SPI_BUS_NUM;

	return NULL;
}

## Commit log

2016-01-18 commit hardware design files
    [Bill of Materials-edison_breakout.xlsx, cc2520_cc2592.SchDoc, cc2538.SchDoc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]
2016-01-19 update schematic
2016-01-27 add some led control python scripts
2016-02-01 add yocto kernel patch hack to disable both chip select line in SPI
2016-02-10 working on publish triumvi data
    better handling threads
    publish to mqtt
2016-02-18 add length check, discard cruppted SPI packet
2016-02-18 add spi length check
2016-02-22 remove sleep(0.01) before sending another spi read instead, read GPIO state to determine if CC2538 is ready
    add a reset counter, once CC2538 keeps sending bogus data
    until certain point, reset it
2016-02-22 increase the spi rate to 2 MHz
2016-02-25 commit start to gps board
    [gps_daughter_board.brd, gps_daughter_board.sch]
2016-04-09 add cad files for case
    includes zortrax project files
    [case_bottom.SLDPRT, case_bottom.STL, case_bottom_v2.STL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]
2016-05-19 update 3d models for case
    [case_bottom.SLDPRT, case_screw_inserts_jig.SLDPRT, case_screw_inserts_jig.STL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]
2016-06-07 add new case models and files
2016-06-17 add case designs
    [case_bottom.SLDPRT, case_bottom_v1.STL, case_bottom_v2.STL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]
2016-06-25 super usage of build plate
2016-07-14 add case picture
2016-07-19 change 'External voltage supply' to 'external voltage waveform'
2016-07-21 remove LED debugging macro
2016-07-27 mraa spi write will potentially stuck when the length is longer than 25-ish split two transactions
2016-07-31 add frame type
2016-10-28 add edison kernel driver modules
2016-11-03 fix gps representation error
    [le910_serial.py]
2016-12-12 add find le910 device script
2016-12-12 add v3 hardware design files
    [BOM-Edison-Gateway-V3.xlsx, antennas.SchDoc, cc2520_cc2592.SchDoc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]
2016-12-12 mv old design file to v2 folder
    [Bill of Materials-edison_breakout.xlsx, cc2520_cc2592.SchDoc, cc2538.SchDoc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]
2017-02-10 add front and back plates
    [plate.SLDPRT, plate_antenna.SLDPRT]
2017-03-22 add calibration coefficient parser
2017-03-30 add AD5304 driver
2017-03-31 add spi mode changing on the fly
2017-03-31 remove print message
2017-05-02 update current interface coefficients
2017-05-07 v2 is actually v3
    [plate.SLDPRT, plate_antenna.SLDPRT]
2017-05-07 better names
    [case_v3_plate_antenna.SLDPRT, case_v3_plate_front.SLDPRT]
2017-05-07 old changes to plates
    [case_v3_plate_antenna.SLDPRT, case_v3_plate_front.SLDPRT]
2017-05-07 add v3 case build files
    [case_v3_plate_antenna_v7.STL, case_v3_plate_front_v7.STL]
2017-06-23 add gateway front/back panel gerber / layout files
    [edison_gateway_v3_back_panel.PcbDoc, edison_gateway_v3_front_panel.PcbDoc, edison_gateway_v3_panels.PcbDoc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]
